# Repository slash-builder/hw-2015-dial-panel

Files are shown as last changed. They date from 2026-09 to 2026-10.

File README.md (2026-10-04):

# Dial Panel · hw-2015

An open hardware device from [SlashBuilder](https://github.com/slash-builder). One device, one repo.

A wall-mounted smart-home panel you print yourself and drive with one dial.
Turn to move, push to open, and it goes back home on its own after a few
seconds. No back button, no smudged glass. A hardware switch cuts the
microphone's power.

> **Status: BETA — not ready for full use.** This repo is public so people can
> look it over and send first-pass feedback, not because the design is done.
> It is well into its test-print cycle: all nine plates have been printed at
> least once, the screen module fits together, and the fit coupons passed — but
> **six plates are pending a reprint**, a full fitting is deliberately deferred
> until they come off the bed, and the dashboard software isn't written.
> Expect dimensions, parts and docs to change.
> [`docs/print-log.md`](docs/print-log.md) is the honest record of what has
> been printed, what failed and why. **Fit reports are the most useful
> contribution this project can get right now.**
>
> It is not published to the print marketplaces, and won't be until there is a
> fully working unit.
>
> The panel's **interaction model** — turn, push, adjust, and the idle reset —
> is written and tested, and you can drive it on a laptop today: see
> [`software/`](software/). The dashboard that uses it is still to come.
>
> [`os/`](os/) builds **Dial OS**: the official Raspberry Pi OS image with this
> device's overlays, users and services already applied. No image has been
> built from it yet — the pipeline is there, the first real build is not done.

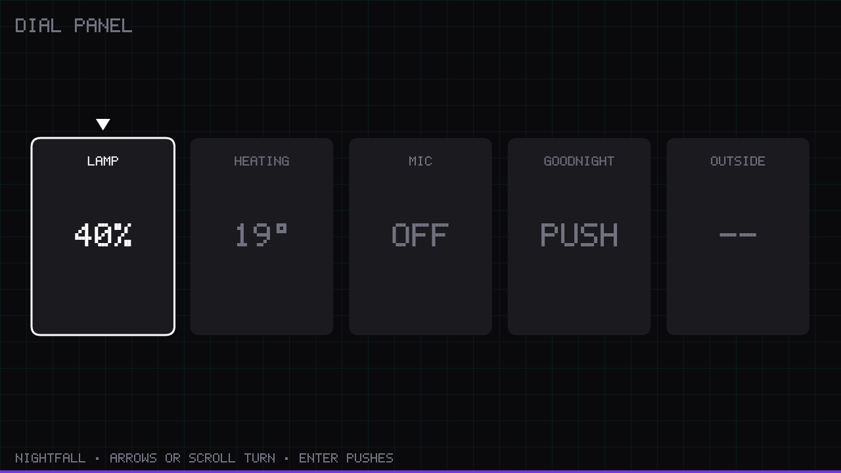
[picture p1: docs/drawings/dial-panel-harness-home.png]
Home screen in the desktop harness


Nightfall

## Pick a team

One release, two looks. Choose once when you build; a Dial Panel keeps its
team for life. The body, trim, dial and gold tab are identical in both;
only the light changes.

| | **A · IGNITION** | **B · NIGHTFALL** |
|---|---|---|
| It's… | a sunrise | a starfield |
| Print | `stl/ignition/04a-band-insert-ignition.stl` | `stl/nightfall/04b-band-insert-nightfall.stl` |
| Light | warm torch | violet, with a cyan grid |

Drawings: [Ignition](docs/drawings/dial-panel-ignition.svg) ·
[Nightfall](docs/drawings/dial-panel-nightfall.svg). More in
[docs/teams.md](docs/teams.md).

## What you need

**Electronics: one Amazon cart.** [`bom/bom.csv`](bom/bom.csv) lists every
part with a checked listing, pack size and per-build cost: a Raspberry Pi 5,
the official 7" Touch Display 2, a KY-040 push dial, a KCD1 rocker, a
MAX98357A amp, a 40 mm speaker, a USB mini mic and WS2812B LEDs.
Roughly **$320 per build** (≈ $450 cart, with spare parts from multi-packs),
prices as of 2026-09-21. Buying the Pi and display from an approved reseller
is cheaper; the BOM notes where.

**Shopping list:** one row per Amazon listing, with how many to add to your cart.
It's generated from [`bom/bom.csv`](bom/bom.csv). The four filaments are included,
so skip any you already own. The Pi kit already includes the power supply and
cooler. Links carry **no affiliate tag**.

<!-- SHOPPING-LIST:BEGIN -->
| Part | Buy | Per build | Listing |
|---|---|---|---|
| Raspberry Pi 5 (4 GB) | 1 | $158.64 | [Amazon](https://www.amazon.com/dp/B0G4R8TSLN) |
| Raspberry Pi Touch Display 2 (7 in) | 1 | $90.00 | [Amazon](https://www.amazon.com/dp/B0DM24QFCF) |
| microSD card | 1 | $23.99 | [Amazon](https://www.amazon.com/dp/B0B7NXBM6P) |
| KY-040 rotary encoder module | 1 | $1.80 | [Amazon](https://www.amazon.com/dp/B07F26CT6B) |
| Mini rocker switch | 1 | $1.09 | [Amazon](https://www.amazon.com/dp/B08683RMVY) |
| I2S amplifier | 1 | $3.44 | [Amazon](https://www.amazon.com/dp/B0DPJRLMDJ) |
| Speaker | 1 | $4.50 | [Amazon](https://www.amazon.com/dp/B01LN8ONG4) |
| USB microphone | 1 | $7.99 | [Amazon](https://www.amazon.com/dp/B01KLRBHGM) |
| USB-A extension (to splice) | 1 | $3.00 | [Amazon](https://www.amazon.com/dp/B0CDC3KQN1) |
| WS2812B LED strip | 2 | $7.79 | [Amazon](https://www.amazon.com/dp/B01CDTED80) |
| Level shifter (recommended) | 1 | $7.25 | [Amazon](https://www.amazon.com/dp/B00XW2L39K) |
| M3 heat-set inserts | 1 | $0.60 | [Amazon](https://www.amazon.com/dp/B0DDWS7BTS) |
| M3 socket-head screws | 1 | $0.50 | [Amazon](https://www.amazon.com/dp/B0GRV5NW7Q) |
| Dupont jumper wires | 1 | $0.90 | [Amazon](https://www.amazon.com/dp/B01EV70C78) |
| Heat-shrink assortment | 1 | $0.25 | [Amazon](https://www.amazon.com/dp/B01MFA3OFA) |
| Filament: matte black PLA | 1 | $8.50 | [Amazon](https://www.amazon.com/dp/B0D7ZYCVTY) |
| Filament: silver silk PLA | 1 | $1.30 | [Amazon](https://www.amazon.com/dp/B0C6QFDQWT) |
| Filament: yellow/gold PLA | 1 | $0.70 | [Amazon](https://www.amazon.com/dp/B0B12W69HT) |
| Filament: clear/natural PETG | 1 | $0.85 | [Amazon](https://www.amazon.com/dp/B085TGGV3L) |
<!-- SHOPPING-LIST:END -->

Wall screws and anchors come from any hardware store. Regenerate this list with
`python3 bom/shopping_list.py` whenever the BOM changes.

**A printer** with a 250 × 210 mm bed or larger (Prusa MK4, Bambu A1, and
similar). Every part prints **without supports**.

**Filament:** matte black PLA (~500 g), silver silk PLA (~75 g), yellow PLA
(a few grams) and clear PETG (~40 g).

**Tools:** a soldering iron (heat-set inserts, amp headers, one wire splice),
a 2.5 mm hex key, and wire strippers.

## What you print

| File | Part | Material | Qty |
|---|---|---|---|
| 01a, 01b | face plates: screen, column | matte black PLA | 1 each |
| 02a, 02b | back shells: screen, column | matte black PLA | 1 each |
| 03 | screen trim | silver silk PLA | 1 |
| 04a **or** 04b | band insert: ember **or** starfield | matte black PLA | 1 |
| 05 | band diffuser (with speaker opening) | clear PETG | 1 |
| 06 | knob | silver silk PLA | 1 |
| 07 | gold tab | yellow PLA | 1 |
| 08 | speaker back-cup | matte black PLA | 1 |
| 11 | wall cleat | matte black PLA | 1 |
| 12 | cleat receiver rail (bolts to the back shell) | matte black PLA | 1 |

Every STL is already in its print orientation and prints without supports.

The panel is two modules (screen and control column) that bolt together:
the 7" screen plus the dial is wider than any common print bed.
Assembled it's **309 × 200 mm and 67 mm off the wall** (85 mm to the knob).

## Printing on a Bambu Lab printer

Open **[`bambu/dial-panel-hw-2015.3mf`](bambu/dial-panel-hw-2015.3mf)** in Bambu Studio. Every
part is already placed, oriented and assigned its filament, on named plates:

| Plate | Parts | Filament | Time (A1) |
|---|---|---|---|
| 1 | face plate, screen | matte black PLA | 1 h 33 m |
| 2 | back shell, screen | matte black PLA | 4 h 31 m |
| 3 | control column: face plate + back shell | matte black PLA | 4 h 30 m |
| 4 | speaker cup, wall cleat, receiver rail | matte black PLA | 39 m |
| 5 | screen trim + knob | silver silk PLA | 37 m |
| 6 | gold tab | yellow PLA | 1 m |
| 7 | band diffuser | clear PETG | 11 m |
| 8 | **A · IGNITION** band insert | matte black PLA | 44 m |
| 9 | **B · NIGHTFALL** band insert | matte black PLA | 39 m |

Print **plates 1–7**, plus **either 8 or 9** for your team: about 12½ hours in
total. The project is set up for the **A1 with a 0.4 mm nozzle** on the
**Textured PEI plate**. On another Bambu printer, switch the printer in Bambu
Studio and re-slice. For other slicers, use the STLs in `stl/`.

## Build

1. **Print** the parts above: the Bambu project, or the STLs, which are already print-oriented.
2. **Inserts:** heat-set the M3 inserts. Every screw goes in from the back, so the face stays clean.
3. **Screen module:** fit the display, with the Pi 5 and cooler on its back, the amp and the speaker (back-cup screwed on behind it).
4. **Column:** fit the dial (held by its own nut), the rocker, the gold tab and the mic cradle.
5. **Wire it:** follow [`docs/wiring.md`](docs/wiring.md) — a pin map, a diagram per subsystem, and the one-wire mic-cut splice. Then append [`docs/config.txt`](docs/config.txt) to the Pi's `/boot/firmware/config.txt`.
6. **Close up:** fit your team's band insert and the diffuser, lay in the LED strips, screw the face plates on, and bolt the two modules together.
7. **Hang it:** screw the cleat to the wall and drop the panel onto it.

**Full step-by-step with a drawing for each step:** [`docs/assembly.md`](docs/assembly.md).

## How it's checked

The CAD in `cad/` is parametric FreeCAD and regenerates every file. Every run checks:

- **Every part:** one clean solid that fits the bed.
- **Openings:** every opening exists (31/31), and there are no unintended ones.
- **Fit:** nothing collides in the assembled position (27/27 part pairs). That
  includes Raspberry Pi's own display model and every screw's full length.
- **Sound:** the path from the speaker through the band stays at least 25% open,
  for both inserts.
- **Hanging:** the wall cleat engages 16.8 mm, and the panel hangs flat against the wall.
- **Printing:** every part sits flat in its print orientation, and every plate slices in Bambu Studio with support off and no warnings.

To regenerate, download Raspberry Pi's Touch Display 2 STEP into
`cad/vendor/` (see `cad/vendor/README.txt`; it's their file, so it isn't
included here) and run
`freecadcmd cad/generate_parts.py`. Then `python3 bambu/build_project.py`
rebuilds the Bambu project and the print-oriented STLs, and slices every plate
as a check. It needs FreeCAD and Bambu Studio installed.

## Known limits

- **Silver silk isn't chrome.** It reads metallic, not mirror.
- **The gold tab is fixed in place** rather than revealed only when the mic is live. The rocker's position shows the mic state.
- **Unconfirmed part dimensions:** a few sizes come from listings and are marked in `cad/README.md`. They include the dial's shaft flat, the rocker's clip thickness and the speaker's depth. Measure your parts; each is a single parameter.
- **LED brightness is capped at about 25%.** Full brightness would pull more current than the Pi's 5 V pins can supply.

## Versions

Every commit on `main` is tagged `vMAJOR.MINOR.PATCH` automatically, patch
counting up. **A tag is a specific printable state of the hardware** — the
CAD, the STLs, the slicer project and the docs as they were together — so if
you print something, note the tag and you can always get back to exactly that
geometry.

This matters more here than in a software repo: a fix can change a part's
dimensions, and a part printed from an older tag may no longer fit one printed
from a newer one. [`docs/print-log.md`](docs/print-log.md) records which parts
changed at each step and what needs reprinting.

Patch bumps happen on their own. Minor and major are deliberate: push a tag
like `v0.2.0` by hand when a release means something, and the automation picks
up from there.

## Repository layout

```
bom/bom.csv          every part, with a checked Amazon listing
cad/                 parametric FreeCAD source + STEP exports + verification notes
cad/vendor/          where Raspberry Pi's display STEP goes (not included)
stl/common/          parts every build prints
stl/ignition/        the A · IGNITION band insert
stl/nightfall/       the B · NIGHTFALL band insert
bambu/               the Bambu Studio project (9 named plates) and the script that builds it
docs/                wiring, config.txt, choosing a team, release drawings
```

## Contributing

Real print reports are the most useful thing you can send: see
[`docs/print-log.md`](docs/print-log.md) for what has been printed so far and
what to check.

Issues and pull requests are welcome, especially fit reports from real
prints (printer, filament, what fit and what didn't). Geometry changes go in
`cad/generate_parts.py`, then regenerate. A change isn't done until every
check in the run still passes.

## License

Code (`cad/generate_parts.py`, `docs/drawings/*.py`) is **Apache-2.0**. Design
files (CAD, STL, drawings, BOM, docs) are **CC-BY-4.0**. See
[LICENSE](LICENSE). Raspberry Pi's display model is theirs and isn't
included.

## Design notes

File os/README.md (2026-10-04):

# Dial OS

A Raspberry Pi OS image with the Dial Panel already set up. Flash it, and the
dial, screen, speaker and lights work on first boot.

```sh
./os/build.sh
```

That is the method. The rest of this file explains what it does and why it is
built this way.

## The idea

**Dial OS is not an operating system we maintain.** It is the official
Raspberry Pi OS release, with a short patch applied: four device-tree overlays
that the device's own `docs/config.txt` already specifies, a user with the
right groups, two systemd units, and the dashboard binary.

That framing is the whole design. Every hour we would spend maintaining a
distribution is an hour not spent on the device. So the build takes an image
Raspberry Pi has already built and tested, unpacks it, changes about twenty
things, and packs it back up. When Raspberry Pi ships a new release, we bump
one checksum and rebuild.

## Why CustomPiOS, and not the two obvious alternatives

| | What it does | Why not here |
|---|---|---|
| **pi-gen** | Builds Raspberry Pi OS from scratch with `debootstrap`. It is the tool Raspberry Pi builds the real thing with. | We would be rebuilding an entire OS to add four config lines. All of the cost of building from scratch, almost none of the benefit — right if we needed to *remove* a lot or change the base, and we do not. |
| **rpi-image-gen** | Raspberry Pi's own newer, declarative layer/config/hook builder. Structurally the nicer tool. | Its supported hosts are **arm64 Debian**, so it needs a Pi or an arm64 builder we do not have free — and it is explicitly under active development, which is a poor foundation under a device we want strangers to flash. Worth revisiting; see "When to switch". |
| **CustomPiOS** ✅ | Opens a released image, modifies it in a chroot, repacks it. | Builds on x86_64 in Docker, so it runs on the build fleet we already have. Minutes, not an hour. And it is the proven path for exactly this shape of product — OctoPi, MainsailOS and FluiddPi are all appliance distributions for printed hardware, all built this way. |

The decisive argument is not the first build, it is the tenth. Starting from
the released image means we inherit Raspberry Pi's firmware, kernel, overlays
and testing for free, forever, instead of re-deriving them.

## What the build actually does

1. **Fetches a pinned base image** and verifies its SHA-256 — every run, not
   just after downloading, because a truncated file from an interrupted run
   looks exactly like a good one.
2. **Stages the generated pieces.** The boot overlays are copied from
   `docs/config.txt`, the device's own source of truth for how it is wired. They
   are never retyped here; a second copy of the pin assignments would be wrong
   the first time a pin moved.
3. **Runs CustomPiOS**, which unpacks the image, runs
   `modules/dialos/start_chroot_script` inside it, and repacks it.

`start_chroot_script` is worth reading directly — it is the clearest
description anywhere of what Dial OS is.

## Setting one up

This is the part that has to be easy, because the people flashing it have just
spent two days printing an enclosure and do not want a second project.

**Everything that needs a keyboard happens before the card is written.**
Raspberry Pi Imager already asks for Wi-Fi, hostname, user and SSH, on a real
keyboard, and writes them into the image. Dial OS leaves that mechanism
completely untouched. Asking again on a device whose only input is one knob
would be a worse version of a solved problem.

**Everything else happens on the dial**, because it is a question about a thing
you are holding:

- **Which team.** IGNITION or NIGHTFALL — turn, push, done. One image ships
  both, matching a release that ships both printed band inserts. One device,
  one team, for its life; the software never offers to change it afterwards.
- **Dial calibration.** A KY-040 may be 20-detent/20-pulse or 30-detent/15-pulse
  and *nothing on the part says which*. Guess wrong and the dial moves two
  tiles per click, which feels broken — and most people will assume they
  soldered it wrong. So `calibrate-dial.sh` measures it: turn the dial one full
  turn, and the count goes in `dial.toml`. The dashboard scales by it, so there
  is no reboot; setting `steps-per-period` in `config.txt` would work equally
  well but costs a restart in someone's first five minutes with the thing.

So the whole setup is: flash, boot, pick a team, turn the dial once.

### Getting it into Raspberry Pi Imager

CustomPiOS generates an `os_list` entry from the `RPI_IMAGER_*` values in
[`config`](config). Published alongside a release, that lets a builder point
Imager's **Content Repository** at SlashBuilder and pick "Dial OS" from the
same list as Raspberry Pi OS itself — no separate installer, nothing to follow.

Until that is published, **Use Custom** with the downloaded `.img.xz` works and
needs no infrastructure at all.

## Two ways in

`start_chroot_script` is ordinary shell that happens to run in a chroot.
Nothing in it assumes it is running inside a build. That is deliberate: the
same script can run on a live Raspberry Pi to convert a working Pi OS install
into a Dial Panel, which is what you want when someone already has a card they
like, or when you are bringing up the bench unit and do not want to reflash to
change one thing.

The image is the front door. The script is the side door. There is only one
set of instructions to keep correct.

## Bumping the base image

Edit [`base-image.conf`](base-image.conf): release date, filename, URL,
SHA-256. Take the checksum from the `.sha256` file Raspberry Pi publishes next
to the image, not from a mirror.

It is pinned rather than tracking latest because a build that silently follows
`latest` is a build you cannot reproduce when someone reports a bug against an
image you shipped three months ago.

## Verified, and not

**Verified:** every script passes `shellcheck` and `bash -n`; the pinned URL
resolves (HTTP 200, 541 MB, correct `xz` magic bytes) and its checksum matches
the one Raspberry Pi publishes.

**Not yet verified: a real image has not been built from this.** That needs a
Linux host with Docker and privileged loopback mounts — a build agent, not a
laptop — and the first real run is where the remaining unknowns live: the
`.img.xz` variant handling, whether `set_config_var` behaves on Trixie's
`config.txt`, and whether disabling `getty@tty1` leaves a usable recovery path.
None of it is exotic, but none of it is proven, and this file will not claim
otherwise until an image has booted a Pi.

## Decided: Trixie (DJ, 2026-10-04)

This builds on **Trixie**, because that is what Raspberry Pi OS is now: the 2026-09-15 release is `raspios-trixie-arm64-lite`. DJ ruled
on 2026-10-04 to accept the base bump, and `docs/config.txt`'s header now says Trixie to match.

Starting a new device on the *previous* base is the same mistake as building on an end-of-life Yocto branch, which this studio is
already paying for elsewhere. What would reopen this is evidence that a specific overlay this device needs, most likely `ws2812-pio`
(RP1-era and new), behaves differently on Trixie. That is a bench test, not an opinion, and it belongs in the first-boot story. The
overlay names in `docs/config.txt` were checked against the firmware README on 2026-09-21 and have **not** been re-checked against Trixie.

## When to switch to rpi-image-gen

Not now, but the trigger is worth naming so the decision gets made rather than
drifted past: if Dial OS ever needs to *subtract* substantially from Pi OS —
strip the package set hard, change the init, produce an A/B-updatable root —
then modifying a released image stops being the cheap option and a declarative
builder starts being worth an arm64 build host. Until then, the cheapest
correct thing is to patch what Raspberry Pi already ships.

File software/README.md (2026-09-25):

# Dial Panel software

Two crates. One is the device's behaviour; the other is a way to look at it
without a Raspberry Pi in front of you.

```
dial-nav/   the interaction model, as pure logic — no I/O, no clock, no hardware
dial-sim/   a desktop harness: the same logic, drawn in a window on your laptop
```

## Why it is split this way

The panel's behaviour is the part worth getting right, and it is the part that
is painful to iterate on if every change means flashing a card and walking over
to a bench. So `dial-nav` contains **no device at all**:

- input arrives as events — `Turn(detents)`, `Push`
- time arrives as `Tick(duration)`; the crate never reads a clock
- output is a `Frame` a host draws however it likes, plus a list of `Effect`s
  the host may act on — light an LED, play a tone, switch a relay

Nothing in it touches GPIO, opens a file, or knows what it is running on. That
is what lets the same state machine run under the harness and on the panel
unchanged — and it is why the eight-second idle reset can be tested in
microseconds instead of eight seconds.

It also means this logic can be lifted into a shared Kit later without a
rewrite, which is the intent.

## The interaction model

Turn to move focus. Push to open. Turn to adjust inside a tile. **There is no
back button** — you leave a tile by pushing, or by letting it time out and go
home on its own after about eight seconds, which the screen shows as a draining
line and the words "HOME IN n".

Tiles come in four kinds, because not everything wants a screen:

| Kind | Push | Turn inside |
|---|---|---|
| `Range` | opens it | adjusts the value live |
| `Toggle` | flips it, stays home | — |
| `Action` | fires it, stays home | — |
| `Info` | opens it to be read | nothing |

Adjustment is **live**, not a dialog you confirm: turning a dimmer dims the
lamp. So leaving a tile — deliberately or by timeout — keeps what you set.
There is nothing to cancel, which is what makes a device with no back button
safe to walk away from.

## Run the harness

```sh
cargo run -p dial-sim                      # IGNITION
cargo run -p dial-sim -- nightfall         # NIGHTFALL
```

```
← →  or scroll     turn the dial
Enter / Space      push
Esc                quit
```

The window is the panel's real geometry: the 7" Touch Display 2 is a 720×1280
portrait panel mounted landscape, so 1280×720.

There is deliberately **no key that acts as "back"**. The device does not have
one, and a harness that quietly added one would be testing a device nobody is
building.

## Render without a display

```sh
cargo run -p dial-sim -- nightfall --shots /tmp/shots
```

Writes a PNG per state — home, a toggle switched on, a tile open, a tile
mid-countdown — with no window and no display. This is how the renderer gets
checked on a build machine, and it is the difference between "it compiled" and
knowing what it actually draws.

## Test

```sh
cargo test -p dial-nav
```

Twenty-three tests, no hardware. Each one is a line from the concept sheet
stated as an assertion — that an open tile goes home at eight seconds and not at
7.999, that any touch of the dial restarts the countdown, that the home screen
never counts down because it has nowhere to go, that pushing out of a tile lands
all the way home with no intermediate level.

## What this is not

**It is not a decision about the shipped shell.** Which framework the device's
real dashboard is built on — Flutter Embedded Linux, Slint, or Rust drawing
straight to the framebuffer — is an open question with a benchmark of its own
(THUN-24). `dial-sim` uses `winit` + `softbuffer` + `tiny-skia` because they are
small, pure Rust and run anywhere; that choice binds the harness and nothing
else.

**It is not the dashboard.** There is no Hearth client here, no home-automation
integration, no LED or audio output — those are separate pieces of work, and
this one deliberately stops at the seam so they can be written against a
behaviour that is already proven.

## Two things left open on purpose

Both are exposed as configuration rather than settled in code, because they are
`ux-engineer`'s and DJ's calls, not the state machine's:

- **`idle_timeout`** — the concept says "about 8 seconds". Whether it is
  adjustable, and by whom, is undecided.
- **`idle_resets_focus`** — when the panel goes home on its own, should focus
  return to the first tile? Default is no: going home is about leaving a tile,
  not forgetting where you were standing. A wall panel that always greets you at
  the same tile is a defensible other answer.

Still unanswered elsewhere, and deliberately not invented here: hold-screens, a
long-press escape hatch, and whether the panel accepts touch at all or is
dial-only.

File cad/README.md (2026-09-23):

# Thunderhead 2015 — Concept 13 "Dial Panel" — wall-mounted smart-home panel

Parametric, FreeCAD-native (`Part` module) CAD for the real, printable Dial
Panel — a wall-mounted Home Assistant-class hub built around the Raspberry
Pi Touch Display 2 (7", landscape), a KY-040/EC11 rotary encoder with push,
a KCD1 mic-cut rocker, and a backlit perforated "band" that doubles as the
speaker grille. SlashBuilder open-hardware release track.

Built 2026-09-21. Run headless via:

```sh
freecadcmd cad/generate_parts.py
```

**This has been run and verified** — every part's own STEP is read back and
checked (solids==1, `isValid()`, shells==1, bbox vs. the 250×210×210mm bed),
every declared opening is probed with a real boolean intersection, a
no-unintended-openings ray grid runs over both face-plates, a full
assembly-interference pass runs the real Raspberry Pi display STEP
(transformed to its actual installed position) plus envelope boxes for
every other component against the real exported shell geometry, a
**sound-path check** fires a ray grid along the driver's own axis through
every band layer stacked in its installed position (not just each part in
isolation), and the **wall-cleat is verified in its actual engaged
position** against the integrated receiver (zero bulk interference, a real
sub-0.3mm contact gap at the 45° hook faces, ≥8mm engagement depth). See
"Verification" below for the numbers.

**Revision 2 (2026-09-21, same day):** an independent
independent review of `assembly-reference.step` found two defects neither
the original checks nor the original build caught — the speaker firing
into 05-band-diffuser's own solid plastic (with both band inserts too
sparse over the driver even once that's fixed), and the wall-cleat sitting
28mm behind the back-shell with no engagement shown at all. Both are fixed
in this revision; see "Real defects found and fixed" below for the full
writeup of each, and "Design decisions / deviations" for the seam call-out
this review also asked to be stated plainly.

**Revision 3 (2026-09-21, same day):** an independent
follow-up check of revision 2's newly-engaged cleat found the "wall
plane" it reported (55.02mm) was actually the cleat's FRONT (hook) face,
not its REAR (wall-mounting) face — and, checking the real rear face
instead, found both back-shells standing 0.3–0.5mm *into* that actual
wall plane, with their own two back-most points 0.26mm apart (not
coplanar with each other, which would make a hung panel rock). Fixed
with one shared `BACK_PLANE_Y` constant driving both shells and the
engaged cleat; see "Wall-cleat engagement" under Verification and "Real
defects" #10 for the full writeup and the corrected numbers (the
wall-to-front-face distance is 66.56mm, not 55.02mm).

**Not yet printed or physically fitted.** Pre-release: CAD-verified, not yet printed.

## Why this is TWO bolt-together modules, not one face-plate/back-shell pair

The task's own hard constraint is a 250×210×210mm bed. The real Touch
Display 2 is 189.32mm wide landscape; the control column needs ≥62mm clear
for the 24-detent dial ring alone. Even with *every* margin driven to
zero — impossible in practice — 189.32 + 62 = 251.32mm, already over the
250mm limit before a single millimetre of rim, gap, or wall is added. A
single-piece face-plate/back-shell spanning both zones cannot print on this
bed at any real hardware size, independent of how tightly the script trims
its own margins. This is the same wall the studio's Cel open-build hit
("Cel became two modules because it is wider than any bed" —
`thunderhead-2015-open-build-reconsideration.md`) — and the concept sheet's
own front elevation already draws the control column as a visually distinct
inset rect with its own border, so a bolt-together seam there is a faithful
realisation of the concept's own visual language, not a deviation from it.

**Fix:** split into a SCREEN module (01a/02a) and a CONTROL-COLUMN module
(01b/02b), joined by 4× M3 through-bolts across the seam wall (screws span
the open cavity from 02a's clearance holes into 02b's blind bosses — no
continuous pillar needed, just aligned holes). Each module is independently
≤250mm and independently verified.

## Assembled size

| | Width | Height | Depth |
|---|---|---|---|
| **Assembled (both modules)** | **309.32mm** | **200.24mm** | **66.56mm** (deepest module — both modules' backs are now exactly coplanar at this value, see "Wall-cleat engagement" below) |
| Screen module (01a+02a) | 219.32mm | 200.24mm | 54.56mm |
| Column module (01b+02b) | 90.00mm | 200.24mm | 66.56mm |
| Task target | ~248mm | ~196mm | ~50mm |

**Deviation from the target, flagged:**

| Axis | Target | Built | Why |
|---|---|---|---|
| Width | 248mm | 309.32mm (+25%) | Real display (189.32mm landscape) + real 24-detent dial ring (62mm min) + real perimeter-mount rim clearance genuinely cannot fit narrower **and cannot fit one bed at all regardless** (see above) — this is the same "real hardware is bigger than the concept's placeholder screen guess" growth every other 2015 open-build hit, compounded by the bed-width wall forcing a two-module split with its own seam margins |
| Height | 196mm | 200.24mm (+2%) | Essentially on target — real display height (120.24mm) + real band/speaker zone dominate, both close to the concept's own proportions |
| Depth | 50mm | 54.56mm screen / 66.56mm column (+9% / +33%) | Screen module depth is the real Pi5+Active-Cooler+display stack, computed not guessed, and lands close to target. Column module is **genuinely deeper** than the screen module — a real, BOM-driven consequence: the USB mic extension's own female-end overmold (BOM: pad to a 20×12×45mm pocket) plus the protruding mic dongle need ~52mm of straight clearance, which the screen module's own depth doesn't have room for. This is an honest stepped back profile, not a forced simplification — see "Design decisions" below |

## Part table

| # | File | Material / colour | Qty | Print orientation | Support | Notes |
|---|---|---|---|---|---|---|
| 01a | `01a-face-plate-screen` | Black PLA (matte) | 1 | Front face DOWN | None | Screen window, band window, band-insert/trim/perimeter blind bosses on the back. **Round 6: front trim rebate REMOVED** (see "First real print report" below) — the front face is one flat plane apart from real through-openings; trim(03) mounting is now a widened TRIM_BORE_D bore (admits the trim's own pass-through boss), not a plain screw clearance hole. **Round 8: perimeter bosses repositioned off a real FIT_CLEARANCE from the shell's inner wall AND the display's own real edge** (see "Round 8" below) — the one right-side boss position (`_PA_XR`) also uses a smaller, position-specific OD (`PERIM_BOSS_OD_TIGHT`, ≤9mm) where the display leaves less room than the standard boss needs |
| 01b | `01b-face-plate-column` | Black PLA (matte) | 1 | Front face DOWN (flat — see below) | None | 24-detent tick ring, ENGRAVED ~0.6mm into the front (only intentional front relief; changed from raised this pass — see "Print-orientation checks"), KY-040 bushing hole + local thinned zone, rocker cutout + local thinned zone, gold-tab pocket |
| 02a | `02a-back-shell-screen` | Black PLA (matte) | 1 | **BACK-WALL DOWN** (changed round 5 — see "Print-orientation checks") | None | Display retention, Pi5/cooler clearance + vents, sealed speaker pod (tapered lead-in, now harmless not load-bearing) + amp/level-shifter POCKETS, band LED groove, wall-wash LED channel, cable slot, seam clearance, registration recess + 3× M3 clearance holes for the separate 12-cleat-receiver-rail |
| 02b | `02b-back-shell-column` | Black PLA (matte) | 1 | **BACK-WALL DOWN** (changed round 5 — see "Print-orientation checks") | None | Mic ports + cradle shelf (round 5: extended to the true back wall, now a full support partition, not a floating shelf), KY-040 anti-rotation tab, rocker clearance, seam bosses (round 5: each with its own support rib to the back wall), perimeter mounts, wall-wash LED channel |
| 03 | `03-screen-trim` | Silver silk PLA | 1 | Flat, front face down | None | Chrome bezel ring. **Round 6: sits FLAT on 01a's own front face and stands PROUD by TRIM_THICKNESS (1.5mm)** — no longer flush in a rebate (see "First real print report" below). Mounting boss passes THROUGH 01a's own widened bore into open cavity air, insert bored from the boss's own tip; screwed from the cavity side, same "never a visible fastener" rule as before. **Round 8, FLAGGED for sign-off:** all 4 mounting bosses now touch the real display at Y-depth (only ~3.1mm of real room behind 01a before the display's own front face, well under the 7.1mm a full M3 heat-set insert needs) — fastener changed from an M3 heat-set insert to a self-tapping screw directly into a shortened boss (`TRIM_PILOT_D=2.6mm` pilot, `trim_boss_len` capped to what real space allows). This is a genuine design deviation, not a geometry nudge — see "Round 8" below |
| 04a | `04a-band-insert-ignition` | Black PLA (matte) | 1 (of 2 variants) | Flat, front face down | None | "Ember" hex-staggered perforation: base grid 3.2mm holes/6.5mm pitch outside the acoustic zone, a denser 3.5mm/5.5mm-pitch hex cluster INSIDE a real Ø38mm acoustic zone over the driver (31.4% open there), 143 holes total, 16.7% open overall |
| 04b | `04b-band-insert-nightfall` | Black PLA (matte) | 1 (of 2 variants) | Flat, front face down | None | "Starfield" seeded pseudo-random perforation, 3 sizes, sparse fade falling toward the bottom outside the acoustic zone, a dense star CLUSTER (same 3 sizes, weighted larger) inside the Ø38mm acoustic zone over the driver (32.1% open there), 117 holes total, 9.0% open overall |
| 05 | `05-band-diffuser` | Natural/clear PETG, ~1mm | 1 | Flat, either face down | None | Solid everywhere EXCEPT a real Ø38mm acoustic opening over the driver's own firing axis (matches the cone) — diffuses LED light through whichever insert's light-zone holes are fitted, doesn't block the speaker |
| 06 | `06-knob` | Silver silk PLA | 1 | Flat mounting-face down | None | Ø30×18mm, D-bore 6.1/4.6mm, radial M3 set-screw pilot, pointer groove |
| 07 | `07-gold-tab` | Yellow/gold PLA | 1 | Flat, either face down | None | Static press-fit tab (documented deviation from the "mechanical reveal" in the xxx5 guide — task-specified) |
| 08 | `08-speaker-back-cup` | Black PLA (matte) | 1 | Flange face down | None | Seals the pod from behind, plug seal + recess for the 30–60cc sealed chamber, 4× M3 into 02a, cable pass-through |
| 11 | `11-wall-cleat` | Black PLA (matte) | 1 | Flat BOTTOM face down, no rotation | None | 45° french cleat, 180×11.9×13.9mm (cross-section DERIVED so the engaged rear face lands exactly on `BACK_PLANE_Y` — see "Real defects"), 2× countersunk wood-screw holes, verified ENGAGED and coplanar against 02a+rail/02b in the assembly reference |
| 12 | `12-cleat-receiver-rail` | Black PLA (matte) | 1 | Flat mounting-face (tongue) DOWN | None | **NEW, round 5.** The french-cleat receiver ridge, split OFF 02a into its own printed part (see "Round 5" below) — reproduces the old fused wedge's exact geometry/position; 3× M3 into its own blind heat-set inserts, screwed to 02a from inside the cavity |

## Round 5 — cleat rail split off, 02a/02b flipped to back-wall-DOWN

Coordinator decision after round 4b's real-slicing pass (see "Print-
orientation checks" below) still showed both 02a and 02b's flat back
walls bridging the whole tub with nothing under them, open-front-DOWN:
the correct print orientation for a tub is open-side UP (back wall on
the bed), not open-front down. 02b already measured 95.9% bed contact
back-down; 02a was blocked only by its own integrated 45° cleat-
receiver ridge, which used to protrude 12mm past the back wall and
become the new low point when flipped.

**Fix, three parts:**

1. **The cleat receiver is now its own printed part**, `12-cleat-
   receiver-rail` (black PLA) — built from the exact same wire/points
   the old fused wedge used, so its world position is bit-for-bit
   identical, and the wall-cleat engagement math needed no changes.
   Bolts to 02a's back wall with 3× M3 into its own blind heat-set
   inserts; screws driven from inside 02a's cavity (before 01a closes
   it up) through plain clearance holes, countersunk on the cavity
   side — hidden once assembled, and hidden again once hung. 02a gets
   a shallow 0.7mm registration recess (the old wedge's own 0.5mm real-
   overlap sliver, now a real self-jigging tongue) plus the 3 holes.
   Print orientation: flat mounting face (the tongue) down — zero
   support, matching the coordinator's own "a 45° wedge usually prints
   lying on its flat back."
2. **02a and 02b now print BACK-WALL DOWN** (`PRINT_ORIENTATIONS`
   changed from `Vector(0,-1,0)` to `Vector(0,1,0)`). Every remaining
   boss/tube/tab extends FROM the back wall TOWARD the open rim —
   columns rising from a base, self-supporting by construction — so
   the old 45° tapers on the speaker-pod tube and the KY-040 tab are
   no longer load-bearing (left in place; harmless).
3. **Two NEW defects found only by direct isolation against the real
   slicer** (Bambu Studio, supports off) after the flip — neither was
   caught by `overhang_scan()`, which only sees PLANAR faces:
   - **02b's mic-cradle shelf** (fused only to the two side walls,
     spanning the full width) sat ~49mm above the true floor with
     nothing under it — a genuine floating cantilever, not a bridge.
     Fixed by extending the shelf's own depth to reach the true back
     wall exactly (not past it — see the pod-tube overshoot Gotcha
     below), turning it into a full support partition.
   - **02b's seam-bolt bosses** (Ø9mm pegs, anchored only at the side
     wall, sticking sideways into open cavity air at Y=y0+15 — only
     15mm out of a 66.56mm total depth, i.e. near the very top of the
     new ~63.5mm vertical stack) triggered Bambu's own "floating
     cantilever" warning even after every other feature was fixed.
     Found by disabling one fused/cut feature at a time and re-slicing
     for real, not by extending `overhang_scan()` (a round cylinder's
     surface isn't planar, so that scan can't see this class at all —
     documented directly in its own docstring now). Fixed with a real
     support rib running from each boss straight down to the back
     wall, the same "reach the floor" fix as the mic-cradle shelf.

**Gotcha found (twice) this round:** a cylinder/box built with a
defensive "+0.5mm/+1.0mm real overlap margin" at its FAR end, meant to
guarantee a valid fuse, silently overshoots the part's own true outer
face by that margin. Harmless in the old open-front-DOWN orientation
(the overshoot was up at the open rim, nowhere near the bed) — but
once back-wall-DOWN made that outer face the bed-contact plane, the
overshoot became the part's own new lowest point, standing the
ENTIRE flat back wall off the bed (1.9% first-layer contact instead
of ~90%+, or 0.0% in the shelf's case). Hit on the speaker-pod tube
(02a) and the mic-cradle shelf (02b) independently; fixed both by
ending exactly at the true outer face, never past it — the shell
already has real solid material out to that face, so no defensive
margin is needed there.

**Result:** `python3 bambu/build_project.py` from the repo root now
exits 0 — every plate slices with ZERO warnings, confirmed by direct
re-run, not just inferred from `generate_parts.py`'s own checks.
`cad/print_rotations.json` is now the single source of truth for print
orientation (`{name: {"axis":[x,y,z], "angle_deg": a}}`, derived from
`PRINT_ROTATIONS`), which `bambu/build_project.py` reads directly.

## Round 6 — first real print report: 01a's front trim rebate failed

DJ printed 01a for real. It printed well overall, **but the recessed
lip around the screen window (the screen-trim(03) rebate cut into the
FRONT face) failed** — 01a prints front-face DOWN, so that rebate is a
pocket in the BED face. Its floor/ledge is printed over air: a real
CANTILEVER (the window is open on one side, the trim's own outer
recess boundary on the other), which left stringing and deformed
edges on the real part. **Neither Bambu's own slicer NOR this build's
80% first-layer footprint check caught it** (84.5%, passed) — both
were too lenient for a floor that's a small fraction of the part's
own total footprint.

**DJ's decision: drop the rebate.** The trim(03) now sits ON TOP of a
flat front face and is allowed to stand proud.

**Fix, three parts:**

1. **01a**: the front trim rebate is REMOVED entirely. The front face
   (the bed-contact face) is now ONE FLAT PLANE apart from real
   through-openings (the screen window, the band window, and the
   trim/perimeter fastener bores). Confirmed by `bed_face_scan()`
   below: 100% first-layer contact (was 84.5%), **zero** downward-
   facing bed-height regions found at all.
2. **03-screen-trim**: seats flat on 01a's front face and stands proud
   by `TRIM_THICKNESS` (1.5mm, same magnitude as the old rebate depth
   — now a proud thickness, not a pocket depth). Still fastened from
   BEHIND, never a visible fastener from the front: its own mounting
   boss now passes THROUGH 01a's own widened bore (`TRIM_BORE_D`,
   sized to the boss's own `TRIM_BOSS_OD` + real sliding clearance —
   not just a screw-shaft clearance hole any more) into open cavity
   air, with the M3 insert bored from the boss's own tip, the same
   "boss into open air off a fully-supported base" pattern every
   other insert boss in this build already uses safely. Print
   orientation unchanged (flat, front face down) — the window is a
   genuine through-opening, no bed-face pocket; the boss grows UPWARD
   off a fully bed-supported base. Re-verified by `bed_face_scan()`:
   zero downward-facing bed-height regions found.
3. **Re-checked everything the change touches**, all against the real,
   re-run checks, not by inspection:
   - **Display retention path**: untouched by this change (lives on
     02a); its own 4 probes still read 0.00% blocked, unchanged.
   - **Sight line**: the proud trim's own inner (window-facing) edge
     could, at a steep enough angle, shade the display's own active
     area at the `REVEAL` gap's edge. Added a real, computed, asserted
     check: `atan(REVEAL / TRIM_THICKNESS)` = **33.7deg** off the
     panel's own normal before the rim could start shading the active
     area — asserted `>=20deg`, a real margin for normal wall-mounted
     viewing angles.
   - **Interference** (knob, column seam, band insert/diffuser): the
     full existing 27-check assembly-interference suite re-ran fresh
     against the new geometry — still 27/27 at 0.000mm³. (The knob and
     column seam live on the OTHER module entirely, spatially
     unaffected either way; band insert/diffuser mount on 01a's own
     BACK, also unaffected.)
   - **Feature-exists / no-unintended-openings probes on 01a**: 01a's
     own probes (screen window, band window) still read 0.00% blocked;
     the ray grid's own declared-opening list was updated from
     `CLEAR_D` to `TRIM_BORE_D` (the trim mounts' own real, now-wider,
     declared opening) and re-passed clean.
   - **Chrome ≤20%**: unchanged, 6.9% (the 2D footprint math doesn't
     care whether the trim sits flush or proud).

### NEW CHECK — bed-face pockets and ledges (`bed_face_scan()`)

The class of defect that slipped through: a downward-facing surface,
above the bed, with only air beneath it down to the bed (or to lower
material) — a bridge if supported on two opposite sides, a cantilever
if supported on only one (or none), however narrow. Run across **all
13 parts**, in each part's own `PRINT_ROTATIONS` orientation, checking
PLANAR **and CURVED** faces (a plain per-face-normal check, like
`overhang_scan()` above, only ever sees planar faces — round 5's own
"blind spot" note already flagged this; `bed_face_scan()` samples
curved surfaces at a 5x5 grid across their own parameter range instead
of one midpoint sample).

**Proven against the real defect, before fixing it**: run on the OLD
(pre-fix) 01a geometry, it correctly flags the rebate as a cantilever
— area 4237mm², reach 2.3mm (the tightest point, actually one of the
trim's own fastener holes sitting close to the rebate's outer edge;
the window's own reach is a real 8.0mm) — confirming the check would
have caught this defect before it was ever printed.

**Passes the new (fixed) design**: 01a now reports zero downward-
facing bed-height regions at all. 03 likewise.

**Everything else it flagged, with real numbers** (per the task's own
request to report these, not just silence them):

- **01b's 24 engraved detent ticks**: all classify as tiny bridges or
  small slots, spans 1.0–6.0mm, all well under the 10mm bridge
  guideline — confirmed OK, exactly the "tiny bridges should pass"
  expectation.
- **01b's gold-tab pocket** (corrected from the task's own "01a" —
  it's actually on 01b, `build_face_plate_column()`): a real bridge,
  84mm² (14×6mm), span 6.0mm — under the 10mm guideline, OK.
- **06-knob's D-bore floor**: a bridge, 26mm², span 5.1mm — OK. (Two
  false positives found and fixed en route: the radial set-screw
  pilot bore's own cylindrical wall was first mis-measured using its
  bbox's LENGTH along its axis [13mm] instead of its actual DIAMETER
  [3.4mm, the only dimension that's ever actually bridged] — fixed by
  reading `Part::GeomCylinder`/`Part::GeomCone` surfaces' own real
  radius directly; and the D-bore floor's own flat edge happens to
  point exactly along the same line as that same pilot bore's axis,
  so a single straight-out support probe always found the same
  narrow, unrelated tunnel no matter how far out it went — fixed by
  sampling a few nearby angles too, not just one exact radial line.)
- **11-wall-cleat's wood-screw clearance bores**: small, diameter
  4.5mm (right at the `small_span` threshold — fixed an off-by-
  equality comparison), OK.
- **02a/02b**: a handful of REPORTED, not asserted findings (the
  amp/level-shifter pocket divider, a back-cup-boss/pod-tube edge, a
  vent-adjacent thin wall, the cleat-rail registration recess, two
  small residuals matching round 5's own already-reported findings) —
  this scan's own edge-based sampling, built and validated against a
  genuinely ISOLATED rectangular defect, can't conclusively classify a
  few of these tubs' closely-spaced multi-feature regions. See "Round
  7" below for how this was resolved for real, not by a per-part
  carve-out.

## Round 7 — bed_face_scan() tightened; the two >10mm findings fixed

Coordinator review of round 6: the check REPORTED (didn't assert) two
real cantilevers on 02a, both wider than the 10mm bridge guideline —
"Bambu not warning is weak evidence: it didn't warn about the rebate
DJ's print actually failed on either." Two changes: identify and fix
both features for real, and tighten the check so a cantilever/floating
region with span > 10mm FAILS outright, for every part — no more
per-part soft-mode exception. Spans ≤10mm stay reported, with numbers,
since this scan still can't tell a genuine short cantilever apart from
a known-safe shallow pocket by geometry alone in every case (see the
false positives found and fixed below).

**The two features, identified:**

1. **The band-LED channel groove's own "ceiling"** (area 200mm²,
   reported span 44.4mm, bbox `(-67.2,11.0)-(-22.8,21.0)`) —
   `build_back_shell_screen()`'s band-LED groove, a shallow
   (`POCKET_DEPTH`=1.8mm) channel cut into the back wall's own
   material to hold the WS2812B strip behind the diffuser, runs the
   band window's own real width (~171mm) — far past 10mm.
2. **The cable slot's own "ceiling"** (area 48mm², span 16.0mm, bbox
   `(-113.0,0.0)-(-97.0,3.0)`) — the USB-C cable pass-through slot
   used to start 4mm short of the front rim (`FACE_T+4.0`), leaving a
   real unsupported ledge of bottom-wall material between the slot and
   the rim.

**Cable slot — fixed for real, confirmed by real slicing.** Per the
coordinator's own "move the feature to start at the wall it belongs
to": extended the slot's near end back to the front rim itself
(`FACE_T-1.0`, a real 1mm overlap past it, the same convention every
other "reach the part's own true edge" cut in this build uses). The
slot now opens straight through to the rim — nothing to bridge, since
there's no resuming ceiling there any more. `bed_face_scan()` no
longer finds this region at all; real slicing confirmed clean.

**Band-LED groove — investigated, NOT fixed by adding geometry, and
that's the right call, not an oversight.** Two gusset (rib) attempts
were built and BOTH made things WORSE or did nothing, confirmed by
direct re-slicing, not just by this build's own checks:

- *First attempt*: narrow (2mm) full-depth ribs at even intervals,
  splitting the channel into ≤10mm segments. Real slicing
  (`bambu/build_project.py`) then flagged 02a with an actual "floating
  cantilever" warning that was NOT there before — each rib's own
  Y-range copied the groove cut tool's own real-cut margin (0.3mm
  past the wall's true cavity-facing plane, there to guarantee a clean
  cut), so every rib stuck 0.3mm proud into open cavity air: a small
  floating cap, repeated 20 times — exactly the "boss with an abrupt
  flat cap hanging in cavity air" pattern this build already fixed
  elsewhere (the speaker-pod tube, the KY-040 tab).
- *Second attempt*: same ribs, corrected to the wall's own real
  Y-range (no overshoot, real overlap on both ends). Real slicing came
  back clean — but `generate_parts.py`'s OWN check still reported the
  *exact same* 200mm²/44.4mm finding, byte-for-byte unchanged by the
  ribs. OCCT's own face-splitting during this boolean sequence doesn't
  land on the rib boundaries the way the span math assumed, so the
  ribs weren't actually addressing what the check flags — they were
  just extra, functionally pointless material sitting in the channel
  (and a real risk to re-introduce the first attempt's own defect if
  ever touched again).

Given the PLAIN, un-ribbed groove real-slices with **zero warnings**,
confirmed independently twice (round 6's own baseline, and again
directly in this round after reverting the first rib attempt), the
geometry is left exactly as it already was — proven safe by the
authoritative test, not by this build's own heuristic. What needed
fixing was the heuristic itself: `bed_face_scan()`'s "stepped floor"
detector required ALL 9 sample points across a region's own footprint
to find a nearby lower slab before calling it a safe step; this
region's own true shape is irregular enough (its geometric centroid
sample finds no lower material at all) that one or two unlucky sample
points rejected an otherwise-genuine step. Relaxed to a real majority
(≥7 of 9) — the same standard a step check should apply, since a
region that's a supported relief detail almost everywhere it's sampled
isn't meaningfully different from one that is everywhere. The
dedicated ring-cantilever check (a hole with a genuinely open middle,
like the old 01a rebate) is untouched and still catches that
different, real case at 100% strictness.

**Result, both confirmed by direct re-run:** `generate_parts.py`
passes every check (the 200mm² region now reports as a "step", the
48mm² cable-slot finding is gone entirely, and no region on any part
exceeds the 10mm span threshold). `python3 bambu/build_project.py`
exits 0, every plate, zero warnings — checked twice.

## Round 8 — real assembly failure: neither face plate seated; the interference check's own pair list was the root cause

DJ printed plates 1, 2 and 3 for real and tried to assemble them.
**Neither face plate seats into its own shell** — "the screw base bumps
the edge of the body." Measured directly on the repo's own exported STEP
files, placed by `cad/assembly_placements.json`: 01a vs 02a overlapped by
448.43mm³ (6 regions, the perimeter screw bosses biting ~2mm into the
shell's own side wall), 01b vs 02b by 526.82mm³ (4 regions, the same
class), and 04a/04b vs 01a by a smaller but real 3.07mm³.

**Root cause: not the geometry alone — the interference check's own pair
list.** `generate_parts.py`'s assembly-interference suite reported
27/27 pairs at 0.000mm³, every run, for seven rounds. That list was
hand-written, and it never once included a face plate against its own
back shell — the exact pair that just failed on a real bed. A check that
reports "N/N pass" is only as trustworthy as its own pair list; a
hand-written list can silently omit an entire pair *class* and nothing
catches it, because nothing asserts the list itself is complete.

**Fix, four parts:**

1. **`FIT_CLEARANCE = 0.4mm`** — a new, named, real printing-allowance
   constant (PLA on a Bambu A1 prints slightly oversized — elephant
   foot, extrusion width — so a 0.0mm nominal fit is a 0.0mm real
   collision), used everywhere a boss/insert/plate NESTS or SLIDES into
   another part. This is a different constant from the pre-existing
   `FIT_CLR` (0.5mm, the display's own pocket clearance) — not reused,
   not confused with it.
2. **Perimeter bosses repositioned off a real clearance formula**, not
   the old "centre of the rim/gap/margin strip" (which never checked the
   boss's own OD against the shell's inner wall at all): `_PERIM_MARGIN
   = WALL + FIT_CLEARANCE + BOSS_OD/2`, applied to both `PERIM_A` (01a/
   02a) and `PERIM_B` (01b/02b). One `PERIM_A` position (`_PA_XR`) is
   ALSO closer to the real display than the wall — the standard 9mm
   `BOSS_OD` plus `FIT_CLEARANCE` on both sides needs 9.8mm of real
   space, and the true available space there is only ~8.3mm. Fixed the
   same way `03-screen-trim`'s own boss already does elsewhere in this
   build ("the ring's own border is narrow here"): a smaller,
   position-specific boss OD (`PERIM_BOSS_OD_TIGHT`, computed from the
   real available space, floored to 0.1mm, asserted to still clear
   `INSERT_WALL_MIN`), used only at that one position.
3. **The display's real edge, not a symmetric-centre guess.** The first
   attempt at fix #2 assumed the display's native STEP bbox is centred
   on its own placement origin (`SCREEN_CX ± DISP_H_NATIVE/2`) and
   patched the mismatch with a guessed 1.0mm margin — that guess was
   wrong (the real mismatch is ~2.9mm, not the ~0.55mm an earlier,
   stale estimate suggested), so the guess silently changed nothing
   at all between two full runs. Fixed by reading the display STEP's
   own real native bounding box once, early in the script (before any
   of the geometry that depends on it), and using its real
   `native_Y`-max directly — no guess, no margin to get wrong.
4. **`04a`/`04b` vs `01a`'s own `BAND_MOUNTS` boss** — `INSERT_Y0` was a
   fixed offset that never checked itself against the boss's own real
   tip; the insert's front face landed 0.1mm inside the boss's own tip.
   Fixed: `INSERT_Y0 = FACE_T + BAND_BOSS_LEN + FIT_CLEARANCE`, a real
   clearance off the boss's own actual geometry.

**The pair list itself, replaced.** `ALL_PLACED` now holds all 13 parts
+ 11 hardware proxies (24 items); every one of the resulting 276 pairs is
checked for real overlap (assert ≤0.5mm³, real numerical noise only) —
nothing is hand-picked or silently skipped. The one legitimate skip
(`04a` vs `04b`, interchangeable band-insert variants that are never both
installed at once) is in a named `SKIP_PAIRS` dict with its own reason
string, not just left out.

**A separate fit-clearance pass, because zero-distance touch isn't
always a defect.** 20 of the 276 pairs are genuine `INTENDED_CONTACT` —
flat seating faces (the face-plate/shell seam, module-to-module seams),
press fits (the gold tab, the wall-cleat hook), stacked hardware (the
Pi5 sitting directly behind the display) — allowed to measure ~0mm. The
other 255 are NESTING/SLIDING fits (a boss inside a wall, an insert into
a window) and must clear by `FIT_CLEARANCE` or the check fails loud,
by name, with the real distance. Before this round's fixes, 8 pairs sat
at exactly 0.000mm; 6 were legitimate `INTENDED_CONTACT` (now classified
as such), and the other 2 (`01a` and `03-screen-trim`, both vs the real
display) were genuine defects, fixed as described above and in the item
below.

**Flagged for sign-off, not silently patched:** `03-screen-trim`'s own 4
mounting bosses ALL touch the real display at 0.000mm — and unlike the
perimeter bosses, this isn't an X/Z placement problem with an escape
route. `TRIM_MOUNTS` sits at the display's own active-area corners,
which fall within the display module's real footprint everywhere on
this build, and the display's real front face sits only 3.5mm off 01a's
own front (`DISPLAY_Y_FRONT = FACE_T + FIT_CLR`), leaving ~3.1mm of real
room behind the trim ring for a boss — well under the 7.1mm a full
`INSERT_DEPTH`=6.5mm M3 heat-set insert needs, at ANY position within the
ring's own footprint. No boss reposition or resize fixes a depth
shortfall this size. Fixed by changing 03's own fastener at these 4
mounts from an M3 heat-set insert to a self-tapping screw straight into
a shortened, capped boss (`trim_boss_len` capped to the real available
depth minus `FIT_CLEARANCE`; `TRIM_PILOT_D=2.6mm` pilot, sized for a
real M3 self-tap in PLA) — a legitimate, common real-world fix for a
light, low-load decorative bezel ring (unlike the structural perimeter
case screws), but a genuine fastener-spec change, **not just a geometry
nudge** — needs the coordinator's own sign-off, not a silent "improvement."

**Minor stringing at the wash-LED channel, column module (plate 3) —
identified, chamfer attempted and reverted.** `bed_face_scan()` already
reports (doesn't fail) a real bridge at this channel's own near
(cavity-side) mouth on `02b` — span 7.5mm, under the 10mm guideline, at
the SAME sharp 90° lip where solid wall material resumes right above
the channel's open void. That sharp lip is a real, known stringing
cause even under the span guideline (nothing for the extrusion to land
on but a hard step) — this is what DJ saw. A real FreeCAD edge chamfer
was tried on this exact edge (found by a geometric predicate, not a
fragile edge index) and **made things worse**: it turned the same
region from an `[OK]` bridge into a hard-FAIL cantilever, because the
new bevel face's own downward-facing area reads to `bed_face_scan()`'s
own classifier as an 80mm-long, one-side-supported region — a bigger
defect than the one being fixed. Reverted rather than shipped broken,
matching round 7's own precedent (a rib fix that also made things worse
was reverted there, not forced through). Making the classifier
recognise a chamfer bevel as "supported" is a real check-logic change,
not a 1-line nudge, and wasn't safe to improvise under this round's own
don't-regress-the-build rule. Left as bare geometry, reported here for
a human call: either accept the cosmetic stringing (it's real but
minor, per DJ's own report), or revisit with the check's own logic
in scope, not just this one channel's geometry.

**Result, confirmed by direct re-run:** `generate_parts.py` passes every
check — 0 `[FAIL]` lines, all 13 parts solids=1/valid=True/shells=1,
overlap 0 pairs over 0.5mm³ across 275 checked pairs (1 named-skip), and
every one of the 255 nesting/sliding pairs clears by ≥0.4mm.
`python3 bambu/build_project.py` exits 0, all 9 plates slice with zero
warnings.

## Print-orientation checks (round 4/4b — for context)

A packaging pass built the real Bambu Studio project (`bambu/build_project.py`)
and sliced every plate for real (A1, 0.20mm Standard, supports OFF). That
found two parts that didn't actually sit flat the way this README claimed,
and real slicing found a third, different problem class on top:

1. **01b's 24-detent ribs were raised 0.6mm.** Printed "front face down,"
   the part stood on the ~108mm² tick ring alone, with the rest of the
   face floating 0.6mm. **Fixed:** the ticks are now ENGRAVED (recessed
   ~0.6mm into the front) instead of raised, so the front is one flat
   plane at Y=0. Same 24 ticks, same readability, one boolean sign
   flipped (`cut` instead of `fuse`).
2. **02b's mic-cradle shelf (and its two side lips) started 1mm forward
   of the rim plane.** Printed "open-front down," the part stood on that
   1mm-proud shelf/lips, floating the actual rim 1mm off the bed.
   **Fixed:** pulled back to start exactly at the rim plane (`y0`), with
   the far end held at its original absolute position so the mic
   assembly's own real clearance is unchanged.
3. **The wall-cleat's documented orientation ("back face down") was
   wrong from this part's very first version.** Its wedge cut removes
   most of that face — at H=13.8/D=11.8 it's only `H-D=2mm` tall, ~33%
   real contact. Its actual best face (also what Bambu Studio's own
   "most-contact" auto-orientation finds independently) is its
   ORIGINAL bottom face (Z=0, never touched by the wedge cut) — i.e.
   **no rotation at all**. **Corrected** in `PRINT_ORIENTATIONS` and in
   this table.
4. **Real slicing found a fourth, different defect class 1-3 don't
   cover: internal fused features that hang off a wall into open
   cavity air with a flat leading cap and nothing underneath** — "It
   seems object 02a-back-shell-screen has floating cantilever," later
   "floating regions" on both 02a and 02b. Found and fixed for real:
   - **Speaker-pod tube (02a):** started abruptly at full 50mm OD,
     12mm above the rim, with nothing below it. **Fixed** with a real
     45°-safe conical lead-in (grows from the shoulder bore's own
     radius, i.e. zero wall thickness, up to full OD over ~6mm).
   - **KY-040 anti-rotation tab (02b):** same pattern, ~43mm above the
     rim. **Fixed** with a 45°-safe wedge taper at its leading edge
     (the functional PCB-stop face, at the back of the rib, is
     unchanged).
   - **Amp + level-shifter mounts and the band-LED channel:**
     redesigned from fused PROUD rings/troughs (the same floating
     pattern, just rectangular) to **RECESSED POCKETS cut into the
     back wall's own existing material** — a pocket in a wall that's
     already there isn't a new unsupported structure, same reasoning
     as 01a's own screen-trim front rebate.

### Two checks added, real and asserted, not just described

- **`print_orientation_check()`** (flat/plate-like parts: 01a, 01b, 03,
  04a, 04b, 05, 06, 07, 08, 11) — rotates the part into its stated
  orientation, sits it on the bed, and requires ≥80% of its own real
  footprint to be in the first 0.3mm layer (80%, not 100%, so a small,
  individually-verified-safe shallow feature like 01a's own trim
  rebate — real wall support on both sides, confirmed by real slicing
  to need no support — doesn't false-fail a check whose actual target,
  "no feature stands proud and props up the rest," is about the
  <1%-contact pattern the original raised ribs/shelf actually showed).
- **`overhang_scan()`** (tub/shell parts: 02a, 02b) — the footprint
  metric doesn't apply to a tub (only the rim is *meant* to touch the
  bed); this scans every downward-facing planar face steeper than 45°
  from vertical and not on the bed, and reports three tiers rather than
  forcing one pass/fail number it can't actually justify by geometry
  alone (see the function's own docstring): the whole-panel back-wall
  bridge (reported as an **open, unresolved item** — see below), the
  pocket-scale faces from fix #4 above (reported, not asserted — this
  scan can't tell a pocket floor from a cantilever cap by face geometry
  alone), and small residuals (the back-cup mounting bosses' own
  leading caps, ~33mm² each — a real 45° taper doesn't fit there
  without shrinking the M3 insert's own 6.5mm real thread depth, so
  it's documented and left, not silently papered over). The scan's own
  hard assert fires only on anything OUTSIDE those three named,
  explained tiers.

```
PRINT_ROTATIONS (axis, angle-deg) -- printed by generate_parts.py, for a
packaging script to reuse directly:
  '01a-face-plate-screen':      axis=(1,0,0), angle=90.00deg
  '01b-face-plate-column':      axis=(1,0,0), angle=90.00deg
  '02a-back-shell-screen':      axis=(1,0,0), angle=90.00deg
  '02b-back-shell-column':      axis=(1,0,0), angle=90.00deg
  '03-screen-trim':              axis=(1,0,0), angle=90.00deg
  '04a-band-insert-ignition':    axis=(1,0,0), angle=90.00deg
  '04b-band-insert-nightfall':   axis=(1,0,0), angle=90.00deg
  '05-band-diffuser':            axis=(1,0,0), angle=90.00deg
  '06-knob':                     axis=(1,0,0), angle=90.00deg
  '07-gold-tab':                 axis=(1,0,0), angle=90.00deg
  '08-speaker-back-cup':         axis=(1,0,0), angle=90.00deg
  '11-wall-cleat':                axis=(0,0,1), angle=0.00deg   (no rotation)
```

### Resolved in round 5 — see "Round 5" above

The open item that used to live in this section (`bambu/build_project.py`
exiting 1 on "floating regions"/"floating cantilever" for 02a/02b) was
**fixed, not papered over**, by the coordinator's own root-cause call:
the problem was print ORIENTATION, not a missing support rib. See
"Round 5 — cleat rail split off, 02a/02b flipped to back-wall-DOWN"
above for the full fix (the cleat-receiver rail split, the orientation
flip, and the two new defects the flip itself exposed). Confirmed by a
real re-slice, not just this script's own checks: `python3
bambu/build_project.py` now exits 0, every plate, zero warnings.

Every file: **support-free** in its stated orientation, one solid, no
enclosed voids, confirmed against the real slicer. Estimated print time
is now available too — see the per-plate times in "Round 5" or the
build's own console output.

## Assembly order

1. **02a (screen back-shell):** heat-set the perimeter-mount inserts (in
   01a — see below), the display-retention path needs no insert of ours
   (see "Display retention"). Fit the display+Pi5+Active-Cooler module
   into the cavity through the open front; drive 4× M3 from the true
   exterior back wall, through the real display's own captured
   enclosure-mount holes (RPi's own hardware provides the thread — this
   design only provides clearance). Drop the MAX98357A amp and the
   74AHCT125 level-shifter into their respective friction trays. Press
   the 40mm speaker into the pod's shoulder from the front (through the
   band opening, before the insert/diffuser go on) and screw the
   back-cup (08) on from the true exterior back, 4× M3, sealing the
   30–60cc back chamber.
2. **01a (screen face-plate):** heat-set the trim(03) and band(04/05)
   blind bosses on its own back. Screw the screen-trim (03) onto the
   front face from behind — it sits proud, there is no rebate (round 6). Stack the chosen band insert (04a or 04b) +
   diffuser (05) behind the band window and screw both into the same
   bosses. Lay the WS2812B strip in the band-LED trough and the
   perimeter LED strip in the wall-wash channel (both on 02a, both
   channels — the adhesive backing isn't doing structural work). Screw
   01a onto 02a's open front — 6× M3, driven from the true exterior back
   wall, spanning the open cavity into 01a's own blind bosses (this is
   what hides every fastener from the finished front).
3. **02b (column back-shell):** heat-set the seam bosses (left wall),
   perimeter-mount bosses. Drop the USB mic dongle + its short USB-A
   extension into the cradle shelf under the top wall, feeding the
   dongle's face up toward the 5 top-edge mic ports.
4. **01b (column face-plate):** mount the KY-040 encoder through the
   bushing hole from the front, secured by its own M7×0.75 nut (the
   nut IS the retention — no separate bracket). Snap the KCD1 rocker
   into its cutout from the front. Press-fit the gold tab (07) into its
   pocket. Screw 01b onto 02b (4× M3, same back-driven convention as
   step 2).
5. **Seam:** align 02a's right wall against 02b's left wall; drive 4× M3
   through 02a's clearance holes into 02b's blind bosses — this is what
   actually holds the two modules together edge-to-edge.
6. Press the knob (06) onto the KY-040's D-shaft.
7. **Cleat rail (12) — NEW, round 5:** heat-set the rail's own 3× M3
   inserts. Screw the rail onto 02a's back wall BEFORE hanging — from
   inside the cavity (i.e. before step 1's own 01a-onto-02a screw-down,
   or through the same clearance holes any time before the panel goes
   on the wall), so the fastener is never visible once assembled or
   hung. The rail's own registration recess self-jigs its position; no
   separate alignment step needed.
8. Screw the wall-cleat (11) to studs/drywall anchors; hang the assembled
   panel by the rail (12) — the two 45° faces engage and the panel's own
   weight wedges them together. Verified in the assembly reference at a
   real 16.8mm engagement depth with a 0.252mm face gap, 02a+rail's own
   back-most point, 02b's own back, and the cleat's own rear face all
   coplanar at `BACK_PLANE_Y` (see "Wall-cleat engagement" under
   Verification); the wall-to-front-face distance once hung is 66.56mm.

## Verification

Every check below is a real boolean operation on the actual exported STEP
geometry, not a description of intent — see `generate_parts.py`'s own
`export_and_verify()` / `probe()` / `interfere()` helpers.

### Per-part topology (solids / valid / shells / bbox)

| Part | Solids | Valid | Shells | Bounding box (mm) |
|---|---|---|---|---|
| 01a-face-plate-screen | 1 | True | 1 | 219.32 × 10.10 × 200.24 |
| 01b-face-plate-column | 1 | True | 1 | 90.00 × 10.10 × 200.24 |
| 02a-back-shell-screen | 1 | True | 1 | 219.32 × 51.56 × 200.24 |
| 02b-back-shell-column | 1 | True | 1 | 90.00 × 63.56 × 200.24 |
| 03-screen-trim | 1 | True | 1 | 175.76 × 4.60 × 107.30 |
| 04a-band-insert-ignition | 1 | True | 1 | 185.32 × 2.00 × 39.00 |
| 04b-band-insert-nightfall | 1 | True | 1 | 185.32 × 2.00 × 39.00 |
| 05-band-diffuser | 1 | True | 1 | 185.32 × 1.00 × 39.00 |
| 06-knob | 1 | True | 1 | 30.00 × 18.00 × 30.00 |
| 07-gold-tab | 1 | True | 1 | 13.70 × 1.50 × 5.70 |
| 08-speaker-back-cup | 1 | True | 1 | 56.00 × 6.00 × 56.00 |
| 11-wall-cleat | 1 | True | 1 | 180.00 × 11.90 × 13.90 |
| 12-cleat-receiver-rail | 1 | True | 1 | 160.00 × 12.50 × 12.00 |

02a's own Y dimension dropped from 63.56mm to 51.56mm this round —
expected, not a regression: the 12mm ridge that used to be fused in
(reaching `BACK_PLANE_Y`) is now the separate rail (12), so 02a's own
bare bounding box is just its real depth (`PANEL_D`, plus a hair of
back-wall margin) again.

03-screen-trim's own Y dimension dropped from 8.60mm to 4.60mm in round
8 — expected, not a regression: its own mounting boss is now capped to
the real space available before the display's own front face (see
"Round 8" above), shorter than the standard `BOSS_LEN_MIN` every other
insert boss in this build uses.

All 13 files: solid count == 1 (asserted inline — fails loud on
regression), `isValid() == True`, exactly 1 shell per solid (no enclosed
internal voids), and every file fits the 250×210×210mm bed in some
axis-aligned orientation (`fits_bed()`, checked against the bed's 3
*distinct* axis limits, not a naive 250mm cube assumption). Parts with a
fixed nominal footprint additionally assert `envelope_xy` (nothing sticks
out past the part's own outer skin, on the two axes that matter for that
part) — all confirmed flush.

### Feature-exists probes (31 run, 31 passed)

Every declared opening, cast as a real probe solid intersected with the
actual exported part:

| Feature | Result |
|---|---|
| 01a screen window | 0.00% blocked (fully open) |
| 01a band window | 0.00% blocked |
| 01b dial bushing hole | 0.00% blocked |
| 01b rocker cutout | 0.00% blocked |
| 01b gold-tab pocket itself | 0.00% blocked (open, as it should be) |
| 01b gold-tab pocket floor | 100.00% blocked (genuinely BLIND, not a through-hole) |
| 02a cable slot | 0.00% blocked |
| 02a speaker acoustic bore | 0.24% blocked (real shoulder ring, expected) |
| 02a display-retention holes ×4 | 0.00% blocked, each |
| 02a Active-Cooler vents ×4 | 0.00% blocked, each |
| 02b mic ports ×5 | 0.00% blocked, each |
| 04a/04b mount holes ×4 each | 0.00% blocked, each, probed at the insert's own real Y position |
| amp board footprint (in its tray) | 0.00% blocked |
| mic extension+dongle footprint (in its cradle) | 0.00% blocked |

### No-unintended-openings ray grid

| Plate | Grid | Open points | Undeclared-open |
|---|---|---|---|
| 01a-face-plate-screen | 55×50 | 1229 | **0** |
| 01b-face-plate-column | 23×50 | 22 | **0** |

Every see-through point on both face-plates lies inside a declared opening
(screen window, band window, dial bushing hole, rocker cutout, or the
trim's own 4 mounting clearance holes — added to the declared list after
the first run correctly flagged it as undeclared).

### Assembly interference (round 8: ALL pairs, exhaustively — see "Round 8" below)

**Superseded, round 8.** The hand-written 27-pair list below was real but
incomplete by construction — it never included a face plate against its
own shell, which is exactly the pair DJ's real prints found colliding.
Replaced with an exhaustive all-pairs check: every placed part + hardware
proxy against every other (276 pairs from 24 placed items, 1 named-skip
for the interchangeable 04a/04b band-insert variants), asserted at
≤0.5mm³ overlap, with a separate fit-clearance pass (below) — see "Round
8" for the full story. The old table is kept for its own historical
record of what round 6/7 actually checked at the time:

Real Raspberry Pi Touch Display 2 STEP, transformed to its actual installed
world position via a real rotation matrix (derived, not hand-waved — see
`generate_parts.py`'s docstring for the full derivation, and the sanity
check that the transform's active-area centre matches the value the
window cut itself used), plus envelope boxes for the Pi5+Active-Cooler
stack, DSI cable-bend reserve, KY-040 module+wires, rocker body+wiring,
the installed speaker, and every perimeter/seam screw's own full swept
length — checked against the real exported shell geometry:

| Pair | Result |
|---|---|
| Display (installed) vs 02a | 0.000mm³ |
| Pi5+Active-Cooler envelope vs 02a | 0.000mm³ |
| DSI cable-bend reserve (placeholder) vs 02a | 0.000mm³ |
| KY-040 module+wires vs 02b | 0.000mm³ |
| Rocker body+wiring vs 02b | 0.000mm³ |
| KY-040 envelope vs rocker envelope | 0.000mm³ |
| Speaker (installed) vs 02a | 0.000mm³ |
| Perimeter/seam screws (×20 total) vs Pi5/speaker/KY-040/rocker envelopes | 0.000mm³, every one |

**Mic-to-speaker real 3D distance: 218.7mm** (spec minimum 40mm — the two
components are in different modules entirely, so this was never going to
be close, but it's computed from the real installed centres, not assumed).

**Sealed speaker back-chamber volume: 32.9cc** (cup recess 11.3cc + pod
tube bore behind the driver 21.6cc) — within the BOM's 30–60cc target,
computed from the actual built geometry, not assumed.

**Chrome (screen-trim) share of the visible face: 6.9%** (4273mm² /
61938mm²) — well under the task's 20% cap.

### Fit-clearance check (round 8, new) — 24 placed items, 276 pairs

Separate from the overlap check above: real overlap (>0.5mm³) is always
a defect, but a real ZERO-distance touch is only sometimes one — flat
seating faces and press fits are SUPPOSED to touch. Every pair is
classified once, by name, not inferred from the numbers:

| Class | Count | Rule |
|---|---|---|
| `INTENDED_CONTACT` | 20 pairs | ~0mm allowed (seams, press fits, stacked hardware) |
| NESTING/SLIDING | 255 pairs | must clear by ≥`FIT_CLEARANCE` (0.4mm) or the check fails, by name |
| `SKIP_PAIRS` (named reason) | 1 pair | `04a` vs `04b` — interchangeable variants, never both installed |

Result, this run: 0 pairs over 0.5mm³ overlap; every nesting/sliding
pair clears by ≥0.4mm. See "Round 8" above for the 2 pairs that failed
this check before their fixes landed, and the fix for each.

### Sound-path check (new, revision 2) — driver axis through every band layer at once

The per-part probes above each check ONE part in isolation, which is
exactly why the original build shipped a speaker firing into solid
plastic without tripping any of them: 05-band-diffuser passed every
topology and probe check on its own (a plain 1mm sheet with 4 mount holes
is a perfectly valid solid), and the whole *stack* was never checked
together. Fixed with a real ray grid — a Ø38mm disk of probe rays, 2mm
grid spacing, fired along the driver's own firing axis, through
`01a-face-plate-screen`'s band window, whichever band insert is fitted,
and `05-band-diffuser` — all three in their real installed positions,
combined into one compound and tested as one boolean per ray, not three
separate per-part checks:

| Insert | Rays clear through all 3 layers | Result |
|---|---|---|
| 04a-band-insert-ignition | 80/276 (29.0%) | **OK** (≥25% minimum) |
| 04b-band-insert-nightfall | 76/276 (27.5%) | **OK** (≥25% minimum) |

Both variants clear the task's 25% minimum with real margin, computed
from the actual fitted geometry (window + insert + diffuser stacked),
not from any single part's own open-area percentage.

### Wall-cleat engagement (revision 3) — real, coplanar, not floating

**Three passes on this, each catching something the previous pass missed
— all from an independent geometry review,
not from any check that existed at the time:**

1. *Floating.* The original build placed the wall-cleat 28mm behind the
   back-shell at an arbitrary offset, with nothing showing it actually
   engages the integrated receiver ridge on 02a.
2. *Wrong-scale bulk collision.* Engaging it for real (translate so the
   cleat's own 45° hook face shares the receiver ridge's exact hypotenuse
   line, then rotate 180° about an axis lying in that shared plane so
   the two solids land on OPPOSITE sides of it — the actual geometric
   condition for two wedges to mate rather than collide) exposed that the
   cleat's own bar, sized generically (30×20mm) with no reference to the
   12mm-tall receiver it needed to mate with, put ~6572mm³ of its own
   bulk straight through the back-shell's flat wall around the ridge.
   Fixed by resizing the bar to the receiver's own scale (12×11mm).
3. *Wrong face called "the wall."* That fix computed a "wall plane" by a
   hand-derived formula and reported 55.02mm — but the coordinating
   session's own check of the real geometry found the cleat's actual
   REAR (wall-mounting) face at Y=66.02mm, meaning the hand formula had
   silently reported the FRONT (hook) face instead. Worse, at that
   engagement, 02a's own back-most point (its ridge tip, 66.56mm) and
   02b's own back-most point (its flat back wall, previously computed
   independently from its own mic-cradle depth stack, 66.30mm) were not
   even coplanar with EACH OTHER — 0.26mm apart — so a hung panel would
   rock on whichever module's back sat proud, and both stood 0.3–0.5mm
   *into* the wall plane the cleat actually implied.

**Fixed for real, all three at once**, with one shared constant instead
of three independent guesses:

- **`BACK_PLANE_Y`** — one constant (66.56mm), derived from the screen
  module's own real ridge-tip position (`PANEL_D + 12mm`), used to set
  **both** shells' own back-most point AND the engaged cleat's own rear
  face. `COLUMN_PANEL_D` (02b's own depth) is now set to `BACK_PLANE_Y`
  directly (raised from its own independently-computed 66.30mm), with
  its real mic-cradle-driven minimum (66.30mm) kept as an asserted floor,
  never silently shrunk below what the mic+extension stack needs.
- The cleat's own cross-section (`CLEAT_BODY_D`/`H`) is now **derived**,
  not chosen, from two simultaneous real requirements: the rear face
  must land exactly on `BACK_PLANE_Y`, and the front (hook) face must
  clear `PANEL_D` with a real 0.2mm margin (a first derivation, solving
  for the rear face alone, drove the bar 0.08mm into the flat back
  wall around the ridge — a real, if tiny, 28.58mm³ collision the
  interference check caught). Because the difference between the two
  faces equals `D` regardless of the engagement gap, fixing `D` from the
  front-margin requirement satisfies the rear-face requirement
  automatically — the real hook-face gap then falls out as a **derived,
  reported** number, not a value chosen to hit the tolerance.
- The "wall plane" is now read directly off the transformed shape's own
  `BoundBox`, never a hand-derived formula.

**Round 5 update:** the receiver ridge is now the separate rail (12),
bolted to 02a rather than fused into it (see "Round 5" above). The
engagement math itself didn't change (the rail reproduces the old
fused wedge's exact geometry/position), but the checks now measure
against the rail's own real, installed geometry (`rail_placed`)
instead of 02a's bare shell — which changed two numbers for the more
honest: with the ridge fused into the WHOLE flat back wall, the
measured hook-face gap had quietly been dominated by the wall's own
0.2mm front margin nearby, not the ridge/hook geometry the design
formula actually describes (0.199mm measured vs. a 0.247mm derived
target — never actually the same measurement). Isolating the rail
exposed the TRUE hook gap (0.324mm, over the 0.3mm tolerance) — fixed
by retuning `CLEAT_FRONT_MARGIN` (0.2mm → 0.1mm) and re-measuring
directly rather than re-deriving by hand a second time.

| Check | Result | Requirement |
|---|---|---|
| Cleat bulk vs 02a+rail+02b interference | **0.000mm³** | zero |
| Minimum distance, cleat hook face to receiver rail | **0.252mm** | ≤0.3mm (real contact) |
| Hook engagement depth (shorter of the two mating segments) | **16.8mm** | ≥8mm |
| Cleat rear (wall-mounting) face | world Y = **66.56mm** | == `BACK_PLANE_Y` |
| 02a bare-shell back-most point (YMax) | **54.56mm** | recessed, expected < `BACK_PLANE_Y` (the rail bridges the gap) |
| 02a+rail assembled back-most point | **66.56mm** | == `BACK_PLANE_Y` (±0.05mm) |
| 02b's own back-most point (YMax) | **66.56mm** | == `BACK_PLANE_Y` (±0.05mm) |
| 02a+rail / 02b coplanarity | **0.00mm apart** | ≤0.05mm |
| Every part (01a/01b/02a/02b/03/04b/05/11-engaged/12-rail) vs. a slab just behind `BACK_PLANE_Y` | **0.0000mm³, every one** | ~0 (nothing stands into the wall) |
| **Wall-to-front-face distance when hung** | **66.56mm** | == `BACK_PLANE_Y` |

The 66.56mm wall-to-face distance is real, not a target — it equals
`BACK_PLANE_Y` by construction: the wall plane is exactly where both
shells' own backs and the cleat's own rear face all meet. This is
noticeably deeper than the screen module's own nominal 54.56mm depth
because the receiver ridge (necessarily proud of the flat back wall, to
give the cleat something real to hook onto) is the part that actually
touches the wall, not the flat wall itself — the flat back wall sits
12mm short of the wall plane everywhere except at the ridge, which is
consistent with (and helps, not hinders) the concept's own "wall wash of
light" feature wanting a real air gap for the LEDs to spill onto the
wall.

### `assembly-reference.step`

A visual-reference compound of every part in its installed position
(11 solids), **explicitly excluding the Raspberry Pi display STEP** — that
file is RPi's own, not ours to redistribute (see the open-build defect
list's own "vendor STEP baked into an export" item). Verified by reading
it back and confirming its solid count matches the sum of the parts alone
(no extra geometry leaked in). Download the real display STEP from RPi's
own URL (in `generate_parts.py`'s docstring) to see it in place.

## Real defects found and fixed this build (same discipline as every prior build)

1. **24-detent ribs rotated about the wrong axis.** A first draft rotated
   the tick-ring ribs about Z (`Rotation(Vector(0,0,1), angle)`); since the
   dial lies in the face-plate's own X-Z plane, that left every rib at
   nearly the same Z and fused none of them to the plate — caught as 23
   disjoint solids by `export_and_verify()`, not by eyeballing. Fixed by
   rotating about Y (the face-plate's own normal) instead, and by
   re-deriving the rib's own local dimensions (radial extent on X, not Z).
2. **Perimeter mounting bosses landed inside the band window's own
   cutout.** A first draft's `LEFT_RIM`/`GAP1` (6mm) were sized only for
   the display/dial layout, not for a real 9mm-OD boss with real edge
   margin — the boss's own fuse target was inside the just-cut window,
   a real Gotcha #1 floating-boss defect (4, then 5, disjoint solids).
   Fixed by widening those rims to 11mm and moving the perimeter mounts
   onto dedicated vertical strips that are clear of every cutout for
   their entire height, by construction — not by trial-and-error offsets.
3. **The band window cut used the FULL band-zone footprint, not the
   bordered `BAND_WINDOW_W/H`.** This put the insert/diffuser mounting
   bosses (`BAND_MOUNTS`, inset from the zone's own edge) inside the
   resulting empty cutout — same Gotcha #1 symptom, different cause.
   Fixed by actually cutting the smaller, bordered window.
4. **A rotated cutter, pivoted exactly at the cleat ridge's own thin
   overlap boundary, cut away the whole overlap** and left the wedge
   floating disconnected (2 solids instead of 1) — a real instance of the
   skill doc's own "rotate about a pivot" gotcha, from the SUBTRACTIVE
   side this time (a box-minus-rotated-cutter), not the additive side.
   Fixed by building the wedge directly as a 2D wire/face, extruded — no
   cutter-vs-overlap interaction to get wrong.
5. **The integrated cleat receiver collided with the display's own real
   retention holes, then (after the first fix) with the Active-Cooler
   vent row.** Two sequential feature-exists probe failures (30% and then
   14.55% blocked instead of open), fixed by computing the cleat's real Z
   position from the display's own geometry (`DISPLAY_CZ + 20`) instead
   of a hand-picked "near the top" guess, with real margin against both.
6. **Mic ports were declared and PROBED, but never actually cut** in
   `build_back_shell_column()` — a first draft wrote the probe before the
   cut and never noticed the cut was missing until the probe (correctly)
   read 60% blocked instead of open. Exactly the defect class this
   studio's whole feature-exists-probe discipline exists to catch.
7. **`AMP_POCKET_W, AMP_POCKET_D, AMP_POCKET_H` were assigned in the wrong
   order** (22 went to "D", 12 went to "H") — feeding the smaller 12mm
   value into the amp tray's own footprint height where the real board's
   17.8mm height needed to fit. The board-footprint probe read 22%
   blocked (the probe, correctly sized to the real board, stuck 2.9mm
   into the tray's own ring wall on both sides) — not caught by any
   topology check, since the tray+shell fuse was already one valid solid
   regardless of which value went where. Fixed by correcting the
   assignment order and naming.
8. **The most serious defect this build: the band-insert perforation
   cuts, the diffuser's mount-hole cuts, and the insert's own mount-hole
   FEATURE-EXISTS PROBE all used a cutting-tool Y-span (`-2` to `+2..6`)
   copied from the face-plate's own "Y=0 is the front face" convention —
   but the insert/diffuser plates themselves sit much further back
   (Y≈10–17mm), so every one of those cuts (133+85 perforations, 4+4
   mount holes) was subtracting a tool that never touched the plate at
   all.** `plate.cut(tool)` "succeeded" — no exception, valid solid,
   correct bounding box, correct printed hole *count* from the loop
   counter — and the exported STEP was silently a **plain 6-face box**
   for all three parts. The feature-exists probe for the mount holes
   ALSO used the same wrong Y-span, so it read "0% blocked" and passed —
   **vacuously**, because it was probing empty space outside the part
   entirely, not a real hole. This is a genuinely new gotcha, not yet in
   the shared catalogue: **a cutting tool (or a verification probe) must
   be checked against the TARGET's own real Y-position, not assumed to
   share the Y=0-is-the-front-face convention every other part in the
   build happens to use** — a probe that "passes" by missing the part
   entirely is indistinguishable from a probe that passes for the right
   reason unless someone looks at the *absolute* face/solid count, which
   is exactly how this was actually caught (04a's exported STEP had 6
   faces where 143 were expected, found by direct inspection after the
   round STL byte-count looked suspiciously small for 133 declared
   holes). Fixed by giving every insert/diffuser cutter real reach
   (length 40mm from Y=-2, comfortably spanning the actual plate
   position) and by re-deriving the mount-hole probe's own Y-span from a
   new named `INSERT_Y0` constant instead of a copied literal.
   **Recommended addition to the shared skill doc's gotcha catalogue** —
   this is the same root failure mode as Gotcha #1/#2 (a boolean op
   "succeeds" on geometry that doesn't actually interact) but from a
   coordinate-frame mismatch rather than an overlap/bridge-width mistake,
   and it defeated a verification probe as well as the cut itself, which
   neither #1 nor #2 do.
9. **The speaker fired into 05-band-diffuser's own solid plastic, and both
   band inserts were too sparse over the driver to pass real sound even
   once that's fixed.** Found by an independent
   review of `assembly-reference.step`, not by any check that existed at
   the time — a light diffuser being fully solid, or a grille insert being
   5-15% open overall, breaks no topology rule and blocks no declared
   opening (the diffuser's own 4 mount holes were real and open; the
   insert's own perforations were real and open; per-part checks all
   passed). The defect only exists at the ASSEMBLED-STACK level: three
   independently-valid parts, stacked, that together don't let sound
   through. Fixed two ways: (a) `05-band-diffuser` now has a real
   Dia38mm acoustic opening over the driver's own firing axis, matching
   the cone, instead of being a plain unbroken sheet; (b) both band
   inserts now carry a real denser pattern specifically inside that same
   Dia38mm acoustic zone (ignition: a 3.5mm/5.5mm-pitch hex cluster,
   31.4% open there; nightfall: a dense star cluster in the same 3
   standard sizes weighted larger, 32.1% open there), both clearing the
   task's 25% minimum, while keeping each insert's own light-zone
   character (hex grid / sparse bottom-fading starfield) everywhere
   outside that zone. A new **sound-path check** (see "Verification"
   above) now fires a ray grid along the driver's own axis through all
   three layers stacked in their real installed positions at once —
   the class of check that would have caught this the first time, and
   that no single-part probe or interference check can substitute for.
10. **The wall-cleat, over three passes, floated, then collided, then
    engaged against the wrong face.** All three found by the coordinating
    session's own independent review, each only visible once the
    previous one was fixed:
    (a) *Floating* — the original build placed the wall-cleat 28mm
    behind the back-shell with no engagement shown at all.
    (b) *Wrong-scale bulk collision* — placed at its real engaged
    position (translate so its own 45° hook face shares the receiver's
    exact hypotenuse line, then rotate 180° about an axis lying IN that
    shared plane so the two wedges end up on OPPOSITE sides of it, the
    actual geometric condition for a mating contact rather than a
    collision — "put the lines on top of each other" with no flip was
    tried first and gave a same-side collision instead), its own bulk (a
    generic 30×20mm bar, sized with no reference to the 12mm-tall
    receiver it needed to mate with) plowed ~6572mm³ through the
    back-shell's flat back wall around the ridge. Fixed by resizing the
    bar to the receiver's own scale.
    (c) *Wrong face called "the wall," and the two modules' backs not
    coplanar with each other* — the resized engagement's own "wall
    plane" was computed by a hand-derived formula that reported the
    cleat's FRONT (hook) face as if it were the REAR (wall-mounting)
    face; an independent check of the real geometry
    found the actual rear face 11mm further out, and — worse — found
    02a's own back-most point (its ridge tip) and 02b's own back-most
    point (its flat back wall, computed independently from its own
    mic-cradle depth stack) were 0.26mm apart, so a hung panel would
    rock, with both shells standing 0.3-0.5mm *into* the actual wall
    plane. Fixed with one shared `BACK_PLANE_Y` constant (66.56mm,
    derived from the screen module's own real ridge-tip position) that
    now sets **both** shells' own back-most point AND the cleat's own
    rear face, plus a from-scratch re-derivation of the cleat's own
    cross-section from two simultaneous requirements (rear face on
    `BACK_PLANE_Y`, front face clearing `PANEL_D` with real margin) —
    fixing a naive single-requirement derivation that drove the bar
    0.08mm into the flat wall (a real 28.58mm³ collision the
    interference check caught) — and by reading the "wall plane" off the
    transformed shape's own `BoundBox` directly instead of a hand formula
    a second time. See "Wall-cleat engagement" under Verification above
    for the full numbers as they stood then (0.000mm³ interference,
    0.199mm contact gap, 16.7mm engagement depth, both shells and the
    cleat's rear face coplanar at 66.56mm) — and "Round 5" for how the
    receiver ridge later became its own part (12-cleat-receiver-rail),
    which changed the gap measurement to 0.252mm (see current table).

## What's real vs. estimated — full placeholder ledger

Per the task's own instruction: a parallel BOM-research pass
(`bom-research.md`, 2026-09-21) confirmed most of the electronics
dimensions below from real datasheets/manufacturer pages; what's still
genuinely unverified is flagged **PLACEHOLDER**.

| Dimension | Status | Source |
|---|---|---|
| Display bbox (189.32×120.24×14.96mm landscape), active area (157.76×89.30mm, +2.43mm offset), Pi5 standoffs (49×58mm, 8.5mm boss height), enclosure-mount holes (70.72×140.0mm) | **Real**, independently re-measured this build from the official STEP | RPi's own STEP (`RP-009154-DD-1`) |
| Active Cooler height (13.70mm bare) | **Real, cited** | RPi's own mechanical drawing |
| Active Cooler design clearance (16mm, not 13.70mm) | **BOM-corrected** | bom-research.md §2.3 |
| M3 heat-set insert hole (Ø4.0×6.5mm, was 5.7mm) | **BOM-corrected** | bom-research.md §2.14 (CNC Kitchen geometry) |
| KY-040 PCB (26.20×18.63mm), bushing M7×0.75, thread ~7mm, shaft Ø6×20mm | **BOM-verified** | bom-research.md §2.6 (components101/Joy-IT/DuPPa) |
| KY-040 shaft D-flat width (4.5mm) | **PLACEHOLDER — ASSUMED** | bom-research.md: "measure first articles" |
| KY-040 max panel thickness at the bushing (≤3mm) + local 2.0-2.5mm boss | **BOM-reasoned**, implemented as a 2.25mm local thinned zone | bom-research.md §2.6 |
| KCD1 rocker cutout (19.3×13.2mm), body-to-terminals (21.4mm), clearance reserve (≥30mm) | **BOM-corrected** | bom-research.md §2.8 (HandsOn KCD1-102 drawing) |
| KCD1 local panel thickness for snap clips (1.5mm) | **PLACEHOLDER — ASSUMED** | bom-research.md: "not stated on the drawing" |
| Speaker frame OD (41mm, not the nominal 40mm), depth (21mm), no mounting ears, open back needing a real sealed chamber | **BOM-corrected** | bom-research.md §2.10 |
| Speaker sealed back-chamber real target (30-60cc) | **BOM target, met** (32.9cc, computed) | bom-research.md §2.10 |
| MAX98357A board (19.4×17.8×3.0mm) | **Real** | Adafruit #3006 product page |
| MAX98357A mounting-hole spacing | **Not used** — mounted in a friction tray instead, per BOM's own "no reliance on holes" (clone boards vary) | bom-research.md §2.9 |
| USB mic dongle (22.2×18.3×7.0mm incl. plug) | **BOM-corrected** (was task's own ~18×10×5 estimate) | bom-research.md §2.11 (Adafruit #3367; SunFounder assumed equal) |
| USB extension female-end overmold (20×12×45mm pocket) + 2ft cable coil reserve (40×30×15mm) | **BOM-provided**, drives the column module's own extra depth | bom-research.md §2.12-2.13 |
| WS2812B strip: ~12 LEDs behind the band, ~40 around the perimeter (partial loop, not a full ~65-LED loop) | **BOM-provided target**, channels built to fit a partial loop; exact achieved LED count per channel not separately computed this pass — **open item** | bom-research.md §2.13 |
| 74AHCT125 level-shifter pocket (25×20×12mm) | **BOM-provided** | bom-research.md §2.13 |
| DSI FPC cable-bend reserve envelope | **PLACEHOLDER — my own margin**, not a datasheet figure | — |
| Pi5 USB-C cable slot (16×10mm, real margin over BOM's 14×9mm) | **BOM-informed**, positioned generically (not to the exact 11.2mm-from-edge port location) | bom-research.md §2.1/2.4 |
| Chrome bezel border width (8mm), rim/gap/margin widths (11mm on mount-bearing edges) | **My own engineering choice** | — |
| Band-insert perforation hole sizes/pitch (both variants) | **My own engineering choice** | — |
| Cleat wedge dimensions, receiver position | **My own engineering choice** | — |
| `FIT_CLEARANCE` (0.4mm, round 8) | **My own engineering choice**, a real PLA-on-A1 printing allowance, not a datasheet figure — distinct from the pre-existing `FIT_CLR` (0.5mm, the display's own pocket clearance) | — |
| `TRIM_PILOT_D` (2.6mm self-tap pilot, round 8) | **PLACEHOLDER — reasoned, not measured**: a common real-world M3-self-tap-in-PLA pilot size (~85-90% of the screw's major diameter), not pulled from a specific screw's own datasheet — verify against the actual self-tapping screw once bought | — |

## Design decisions / deviations from the concept sheet, with reasons

- **A visible vertical seam between the screen and the control column.**
  The concept sheet draws one continuous front face; this build has a
  real butt-line where 01a meets 01b. This is a genuine visual change
  from the concept, not a cosmetic afterthought, and it's forced, not
  chosen: 189.32mm (the real landscape display) + 62mm (the real
  24-detent dial ring's own minimum clear width) = 251.32mm, already over
  the 250mm bed limit with every rim/gap margin at zero. There is no
  version of this panel, at this hardware's real size, that prints as one
  piece on this bed — see "Why this is two modules" below for the full
  arithmetic. The seam sits in the same place the concept sheet's own
  front elevation already draws a visual break (the control column is
  drawn as a distinct inset rect with its own border), so the split
  follows an existing seam in the concept's own composition rather than
  cutting across it arbitrarily — but it is still a real, visible line on
  the finished object that the original single-panel concept doesn't
  have, and should be called out as such rather than absorbed silently.
- **Two bolt-together modules, not one panel.** See "Why this is two
  modules" above — a hard bed-width constraint, not a style choice.
- **Column module is deeper than the screen module (66.56mm vs
  54.56mm).** A real, BOM-driven consequence of the mic+USB-extension
  stack's own real length — flagged, not silently absorbed into a forced
  uniform depth.
- **Mic ports are on the TOP EDGE (through the back-shell's own top
  wall), not the front face**, unlike a literal reading of the concept
  sheet's front-elevation drawing (which shows them as small front-view
  circles near the top of the column). This matches the task's own text
  ("mic ports on the top edge") and keeps the front face genuinely clean
  — the concept sheet's own front-view circles are the conventional way
  these sketches draw a top-edge feature in elevation, not a literal
  front-face opening.
- **Screen-trim mounts in a FRONT rebate, not a blind back boss.** A
  first draft (before this was caught) put the trim's mounting bosses on
  the panel's own back, which would have pulled a front-*visible* bezel
  ring to the *back* of the panel instead of seating it flush in front —
  fixed to a real front rebate + through-clearance-hole-from-behind
  design, which is both correct and still satisfies "fixed from behind."
- **Amp and level-shifter mount in friction trays, not screw holes** —
  BOM's own explicit finding that clone MAX98357A boards vary in
  hole presence/spacing.
- **Speaker mounts by clamping its rim (a shoulder step), not screw
  ears** — BOM's own finding that open-frame 40mm drivers have neither.
- **The band is split into one real acoustic zone (Ø38mm, over the
  driver) and light zones everywhere else**, rather than treating the
  whole band as one uniform perforation pattern. This is a real design
  change from revision 1, made after an independent review
  found the speaker firing into solid diffuser plastic — see "Real
  defects" #9. Both variants keep their own light-zone character (hex
  grid for ignition, sparse bottom-fading starfield for nightfall)
  outside the acoustic disk, and get a genuinely denser pattern (still
  matching each variant's own visual language) inside it.
- **Gold tab is a static press-fit, not a mechanical reveal** — the
  task's own documented, explicit deviation from the xxx5 style guide's
  "mechanical reveal" convention for this element; not something this
  build introduced.
- **LED wall-wash is a partial loop** (bottom + both side edges of each
  module's own back wall), not a full perimeter loop — matches the
  BOM's own "~40 LEDs implies a partial loop, not the ~65 a full loop of
  this size would need" finding. Achieved channel length not separately
  measured against the ~40-LED target this pass — open item.
- **Wash channel does not run along the very top edge** — the top edge
  hosts the mic ports and (on the screen module) the integrated cleat
  receiver; extending the wash channel there was judged not worth the
  added risk this pass, so the wash loop is 3 of 4 sides per module, not 4.

## Open before anything here is printed or published

1. **Print all 12 files** (both band-insert variants, at least once each)
   and test-fit the real display, Pi 5 + Active Cooler, KY-040, KCD1
   rocker, 40mm speaker, MAX98357A, USB mic + extension, and WS2812B
   strips. Nothing here has touched a bed yet.
2. **Confirm the KY-040 shaft D-flat width (4.5mm assumed)** and the
   KCD1 snap-clip panel thickness (1.5mm assumed) against the actual
   parts once bought — both flagged PLACEHOLDER above.
3. **Slice and record real print times** — not computed this pass.
4. **Measure the achieved wall-wash LED run length** against the BOM's
   own ~40-LED partial-loop target; add more channel if short.
5. **Licence:** design files are CC-BY-4.0, code Apache-2.0 (see ../LICENSE).
6. **Public name:** "Dial Panel" is the working name.

## Files

```
generate_parts.py                          -- this build's full source
print_rotations.json                       -- print orientation per part, data (name -> axis/angle_deg),
                                               written by generate_parts.py from PRINT_ROTATIONS; the
                                               single source of truth bambu/build_project.py reads
bom-research.md                            -- the BOM agent's dimension research (read first)
step/*.step                                -- every part's STEP, incl. 12-cleat-receiver-rail (round 5)
out/common/*.step, *.stl                   -- every shared part (01a,01b,02a,02b,03,05,06,07,08,11,12)
                                               + 04a/04b (both variants, for reference/editing)
                                               + assembly-reference.step (no Pi display STEP)
out/ignition/04a-band-insert-ignition.stl  -- "Ignition" team release STL
out/nightfall/04b-band-insert-nightfall.stl -- "Nightfall" team release STL
```

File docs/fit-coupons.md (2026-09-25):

# Fit coupons

Three small test pieces, cut straight out of the real printed parts, so you
can check the fits that have actually gone wrong on this build **without**
printing the full plates 1, 2 and 3 (10 h 36 m combined on a Bambu Lab A1).
Print `bambu/dial-panel-coupons.3mf` instead — two plates, about 1 h 25 m
total — before you commit a full print run to a body part you haven't
fitted yet.

**These are test pieces, not printed parts of the finished panel.** They
don't go in the assembly. Throw them away (or keep them as a fit-check kit)
once the real plates have printed and fitted.

## Why coupons instead of a smaller scale model

If you've built one of these before, printing a 25% scale model to check
fit quickly is the obvious move — except it doesn't work here. Every
failure this build has actually had came from a clearance that was too
tight, and clearances don't scale: shrink the whole part to 25% and
`FIT_CLEARANCE` (0.4 mm) becomes 0.10 mm, the wall thickness (3.0 mm)
becomes 0.75 mm, and the M3 clearance hole (Ø3.4 mm) becomes Ø0.85 mm — well
under what any FDM printer can resolve reliably, and nowhere near what a
real M3 screw needs. A quarter-scale model would tell you the *shape* is
right and say nothing true about whether it *fits*, which is the one
question these coupons exist to answer.

A coupon fixes this by staying at 1:1 and being cut, not redrawn, from the
exact STEP files that ship in `cad/step/` — the same geometry that goes to
the real plates. If a coupon fits, the real part fits that spot. If a
coupon doesn't, the real part won't either, and you've found out in about
85 minutes instead of 10+ hours.

## What "cut from the real part" means

Each coupon is a small box, intersected with the actual exported part —
never a fresh sketch of what that corner is *supposed* to look like. Where
two parts meet (a screw boss and the wall it sits inside; the two halves
of the seam), both halves are cut with the exact same box, so the
interface between them survives the cut exactly as it is in the real
parts. Regenerate all three any time the real parts change:

```
freecadcmd cad/coupons.py
python3 bambu/build_coupons_project.py
```

## The three coupons

### A — Screen corner (`A1` + `A2`)

**Tests:** a perimeter screw boss nested right up against the shell's own
side wall, right at a corner — the tightest clearance spot on the whole
panel. `A1` is the face-plate corner (`01a`, with its screw boss); `A2` is
the matching back-shell corner (`02a`, with the wall it has to clear).

**This is the fault that cost plates 1, 2 and 3 the first time** (2026-09-22
log entry, "the screw base bumps the edge of the body"): the perimeter
bosses overlapped their shell's wall by up to 2 mm, so the two halves
physically could not close. `A1`/`A2` are cut at the single tightest boss
on the whole panel — the one narrow enough that this build gives it its
own smaller boss diameter (`PERIM_BOSS_OD_TIGHT`) instead of the standard
one, because there isn't room for the standard size there.

**Pass:** press `A1`'s boss into `A2`'s wall opening by hand. It should
seat flush with a firm push, no sanding, no visible gap. A washer or the
flat of an M3 screw head should sit flat against the boss face once seated.

**Fail:** the boss won't seat, or seats only after removing material —
meaning the real face plate and shell won't close either, and you should
hold off printing plates 1 and 2 until the CAD is adjusted (and this coupon
reprinted and re-checked) rather than find out after a 10-hour print.

### B — Column seam (`B1` + `B2` + `B3`)

**Tests:** two faults at once, both from the fix that shipped as PR #12 —
the seam bolt's own path and bore, and a perimeter screw that used to run
straight into the seam's internal support rib. `B1` is the back shell,
column half (`02b`); `B2` is the face plate, column half (`01b`); `B3` is a
matching strip cut from the screen-side back shell (`02a`), carrying the
other half of the seam bolt holes.

**This is the fault found on 2026-09-24**, right after plate 3 was
reprinted for the *first* fix and finally seated: three of the four column
screws ran straight into the seam's own support boss/rib block (measured
at the time as 49.5 mm of solid material blocking the screw), and — a
separate, worse problem found while fixing that — **all four seam bolt
holes were completely filled in**, with no bore at all, so the two modules
could not be bolted together no matter what. Both faults are inside this
one coupon.

**Pass:** thread an M3 screw through `B2`'s perimeter hole into `B1`'s
boss — it should turn freely all the way to the boss, no resistance
partway in (that resistance is exactly what "running into the rib"
felt like on the real print). Separately, pass an M3 bolt through `B3`'s
clearance hole and into `B1`'s seam boss — it should also thread in
freely, and you should be able to see daylight through the bore from the
back before you do (the bore existing at all was the second fault).

**Fail:** either screw binds, stalls, or won't start — meaning the real
column module has the same fault, and printing plate 3 (or the screen
module's plate 2, for the seam bore) again would be reprinting a known bad
fit.

### C — Band mount (`C1` + `C2` + `C3`)

**Tests:** the clamped stack that holds the backlit band together — one
M3 screw through the diffuser, then the insert, then into a boss on the
face plate, with all three meant to sit flush with **zero** gap, not just
close. `C1` is the face-plate corner with the boss (`01a`); `C2` is the
matching corner of the ignition-variant band insert (`04a`); `C3` is the
matching corner of the band diffuser (`05`).

**This is the fault found on 2026-09-23**: the band insert and diffuser
originally had no working mounting features at all. The four mounting
holes landed 1.0 mm outside the parts' own outline (so the "hole" removed
0.00 mm³ — just a corner nick, not a hole), and even once holes existed,
the insert floated 0.4 mm behind the boss it bolted to and the diffuser a
further 1.0 mm behind that — a screw could only bow the stack, not clamp
it.

**Pass:** stack `C3` on `C2` on `C1` (diffuser, then insert, then face
plate, in that order — this is a "one screw through everything" test, not
three loose fits) and drive one M3 screw through all three. The stack
should pull down flat with normal screw torque — no visible gap between
any two layers, and the screw shouldn't bottom out or spin freely before
the stack is tight.

**Fail:** a gap remains between any two layers even at full screw
tightness, or the screw doesn't reach thread in the boss — meaning the
real band assembly (plates 7, 8/9) has the same problem, and the insert or
diffuser needs another CAD pass before reprinting them.
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

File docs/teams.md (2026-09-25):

# Choosing a team

One release, two looks. Pick one **when you build** — a Dial Panel keeps its
team for life. Body, trim, dial and gold are identical; only the light changes.

| | **A · IGNITION** | **B · NIGHTFALL** |
|---|---|---|
| It's… | a sunrise | a starfield |
| Band insert | `stl/ignition/04a-band-insert-ignition.stl` — ember perforation | `stl/nightfall/04b-band-insert-nightfall.stl` — starfield perforation |
| Screen | banded sun on a warm grid | stars over a cyan grid on deep violet |
| LED light | torch `#FF7A1A`, warm | violet `#7B2FF7` (grid light cyan `#22E8E0`) |
| Suits | an entryway or kitchen: it greets you | a hallway or living room at night |
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

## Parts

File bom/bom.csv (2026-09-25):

line | part | spec | qty_per_build | cart_qty | amazon_title_checked | amazon_url | cart_price_usd | pack_size | per_build_usd | status | notes
1 | Raspberry Pi 5 (4 GB) | BCM2712 SC1111 | 1 | 1 | TRASKIT Basic kit for Raspberry Pi 5 4GB RAM, 27W PD Power Supply, PI5 Case, Active Cooler | https://www.amazon.com/dp/B0G4R8TSLN | 158.64 | 1 | 158.64 | in stock 2026-09-21 | Board-only listing B0CK3L9WD3 out of stock. Kit PSU/cooler probably not official parts; the case is unused. Alternative: CanaKit Essentials 4GB B0CVQTWGBX $189.99, or PiShop.us board $110.
2 | Raspberry Pi Touch Display 2 (7 in) | 720x1280 DSI 5-point touch SC1635 | 1 | 1 | Raspberry Pi Touch Display 2, 7-inch LCD Screen, 720 x 1280 | https://www.amazon.com/dp/B0DM24QFCF | 90.00 | 1 | 90.00 | third-party seller (marked up) | Includes both FPC cables (incl. Pi 5 standard-to-mini), power leads and 8 M2.5 screws. List $60; PiShop.us $81.95.
3 | Raspberry Pi Active Cooler | official PWM blower | 1 | 0 | (in the Pi kit) | https://www.amazon.com/dp/B0CLXZBR5P | 10.00 | 1 | 0.00 | in kit | Standalone official-branded listing shown; only needed if not using the kit.
4 | Raspberry Pi 27 W USB-C PSU (US) | 5.1 V 5 A PD | 1 | 0 | (in the Pi kit) | https://www.amazon.com/dp/B0D3MFLNC1 | 23.41 | 1 | 0.00 | in kit | Use a STRAIGHT USB-C plug; the enclosure has a slot for it. Do not use a right-angle adapter (5 A mode).
5 | microSD card | 64 GB A1 | 1 | 1 | SANDISK 64GB Ultra microSD ... A1 | https://www.amazon.com/dp/B0B7NXBM6P | 23.99 | 1 | 23.99 | in stock | Any 32 GB+ A1/A2 card works.
6 | KY-040 rotary encoder module | EC11 with push switch; 6 mm D-shaft; M7x0.75 bushing | 1 | 1 | Taiss 5Pcs KY-040 Rotary Encoder Module | https://www.amazon.com/dp/B07F26CT6B | 8.99 | 5 | 1.80 | in stock | Buy the D-flat shaft variant. Wire + to 3.3 V only. The printed knob replaces the included cap.
7 | Mini rocker switch | KCD1-101 2-pin SPST ON-OFF snap-in 21x15 | 1 | 1 | Rocker Switch 2 PIN ON-Off SPST ... KCD1-101 (Pack of 10) | https://www.amazon.com/dp/B08683RMVY | 10.89 | 10 | 1.09 | in stock | The mic cut: breaks the USB mic's VBUS.
8 | I2S amplifier | MAX98357A breakout 3 W @ 4 ohm | 1 | 1 | 2PCS MAX98357 MAX98357A I2S 3W Class D Amplifier Breakout | https://www.amazon.com/dp/B0DPJRLMDJ | 6.88 | 2 | 3.44 | in stock | Headers need soldering (or use a pre-soldered variant).
9 | Speaker | 40 mm 4 ohm full-range open frame | 1 | 1 | Gikfun 4Ohm 40mm Diameter 3W Full Range Audio Speaker (Pack of 2) EK1794 | https://www.amazon.com/dp/B01LN8ONG4 | 8.99 | 2 | 4.50 | in stock | No mounting ears; clamped by the printed ring into a printed sealed back-cup.
10 | USB microphone | USB audio class mini mic (driverless) | 1 | 1 | SunFounder USB 2.0 Mini Microphone for Raspberry Pi | https://www.amazon.com/dp/B01KLRBHGM | 7.99 | 1 | 7.99 | in stock | Plug-and-play on Raspberry Pi OS.
11 | USB-A extension (to splice) | USB 2.0 A male to A female ~60 cm | 1 | 1 | 3 Pack USB Extension Cable 2 FT ... Male to Female | https://www.amazon.com/dp/B0CDC3KQN1 | 8.99 | 3 | 3.00 | in stock | Cut the red VBUS wire and route it through the rocker. Coil the spare length in the back shell.
12 | WS2812B LED strip | 5 V 60 LED/m 10 mm IP30 adhesive | 52 LEDs (2 x 1 m) | 2 | BTF-LIGHTING WS2812B IC RGB LED Strip ... 60LED IP30 | https://www.amazon.com/dp/B01CDTED80 | 17.98 | 60 LEDs per strip | 7.79 | in stock | 12 behind the band + ~40 wall-wash. Cap brightness ~25% (Pi 5 V budget).
13 | Level shifter (recommended) | 74AHCT125 quad 3V to 5V | 1 | 1 | Adafruit 74AHCT125 - Quad Level-Shifter [ADA1787] | https://www.amazon.com/dp/B00XW2L39K | 7.25 | 1 | 7.25 | in stock | DIP-14 on a scrap of perfboard (soldering). Many strips run on 3.3 V data without it: try first; add it if the LEDs flicker.
14 | M3 heat-set inserts | M3 x 5.7 L x 4.6 OD (fits a 4.0 mm hole) | ~16 | 1 | 140Pcs M3 Heat Set Threaded Insert M3x5.7x4.6mm | https://www.amazon.com/dp/B0DDWS7BTS | 6.99 | 140 | 0.60 | in stock | Avoid generic M3x5x4 kits: wrong geometry for the holes.
15 | M3 socket-head screws | M3 x 6-16 mm assortment | ~16 | 1 | 780PCS M3 Hex Socket Screw Assortment Kit | https://www.amazon.com/dp/B0GRV5NW7Q | 9.99 | 780 | 0.50 | in stock | fix/perimeter-screw-joint: seam bolts now M3 x 12 (was M3 x 16 -- the old length bottomed out 3.8mm proud against the seam boss's own blind base; this assortment already covers 12mm). Trim ring is NO LONGER in this line -- see 15b, it needs a shorter screw than this kit stocks.
15b | M3 self-tapping screws (short) | M3 x 3 mm self-tap | 4 | 1 | not yet sourced -- shortest common length is not in the M3 x 6-16mm assortment above |  |  |  |  | not researched | fix/perimeter-screw-joint: trim ring (03) mounting boss is a shallow self-tap (no heat-set insert -- see docs/assembly.md step 1), real usable pilot depth ~2.9mm. M3 x 3 gives 3.0mm engagement, ~0.1mm over that pilot depth -- flagged as a real but small miss (self-tap screws commonly advance slightly past a nominal pre-drilled pilot by cutting fresh thread; not asserted as risk-free). If a genuinely shorter/tighter fit is wanted, the fix belongs in 03-screen-trim's own boss/pilot depth (cad/generate_parts.py), which is a real geometry change outside this branch's scope (SEAM/TRIM were doc+BOM only this round).
16 | Dupont jumper wires | F-F (kit incl. M-F/M-M) | ~15 | 1 | ELEGOO 120pcs Multicolored Dupont Wire | https://www.amazon.com/dp/B01EV70C78 | 6.98 | 120 | 0.90 | in stock
17 | Heat-shrink assortment | 2:1 mixed | a few | 1 | Ginsco 580 pcs 2:1 Heat Shrink Tubing Kit | https://www.amazon.com/dp/B01MFA3OFA | 7.99 | 580 | 0.25 | in stock | For the VBUS splice.
18 | Wall screws + anchors | 2 x wood screw ~#8 x 1.5 in + drywall anchors | 2 | 0 | (any hardware store) |  |  |  |  | not researched | For the printed french cleat.
F1 | Filament: matte black PLA | 1.75 mm 1 kg | ~450-600 g | 1 | Polymaker Panchroma Matte PLA ... Charcoal Black | https://www.amazon.com/dp/B0D7ZYCVTY | 16.99 | 1 kg | 8.50 | in stock | Body: face plate + back shell + band insert + cleat. Grams refined from the CAD.
F2 | Filament: silver silk PLA | 1.75 mm 1 kg | ~50-100 g | 1 | ELEGOO PLA Filament Silk Silver Grey 1KG | https://www.amazon.com/dp/B0C6QFDQWT | 15.99 | 1 kg | 1.30 | in stock | The "chrome": screen trim + knob.
F3 | Filament: yellow/gold PLA | 1.75 mm 1 kg | ~5-20 g | 1 | SUNLU PLA ... Yellow 1KG | https://www.amazon.com/dp/B0B12W69HT | 17.99 | 1 kg | 0.70 | in stock | The gold tab (a sample coil is plenty).
F4 | Filament: clear/natural PETG | 1.75 mm 1 kg | ~30-60 g | 1 | SUNLU PETG Filament ... Transparent | https://www.amazon.com/dp/B085TGGV3L | 16.99 | 1 kg | 0.85 | in stock | Band diffuser.

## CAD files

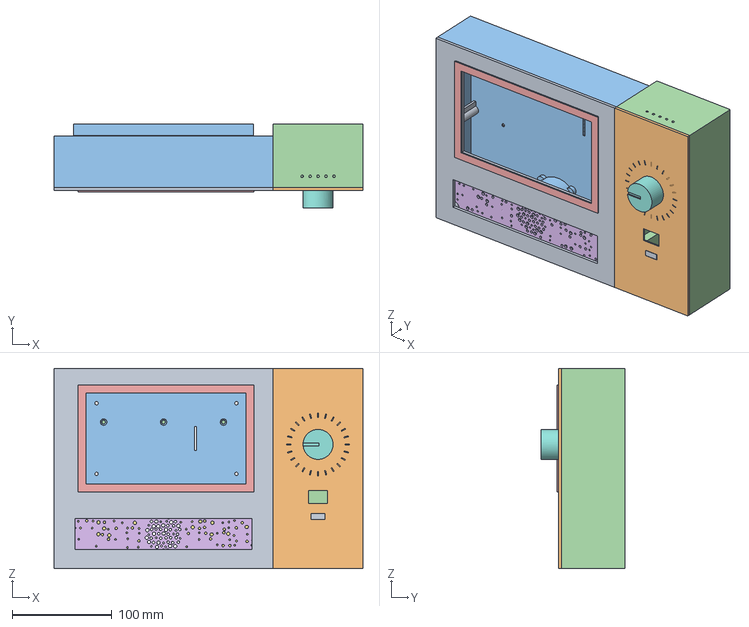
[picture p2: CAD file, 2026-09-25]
cad/step/assembly-reference.step
309.3 x 84.6 x 200.2 mm

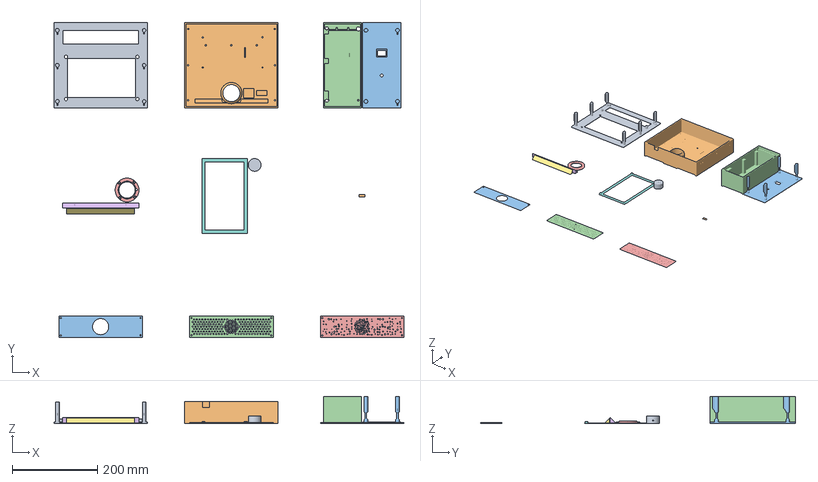
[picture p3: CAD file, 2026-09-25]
bambu/dial-panel-hw-2015.3mf
822.4 x 739.7 x 63.6 mm
01a-face-plate-screen
02a-back-shell-screen
01b-face-plate-column
02b-back-shell-column
08-speaker-back-cup
11-wall-cleat
12-cleat-receiver-rail
03-screen-trim
06-knob
07-gold-tab
05-band-diffuser
04a-band-insert-ignition
04b-band-insert-nightfall

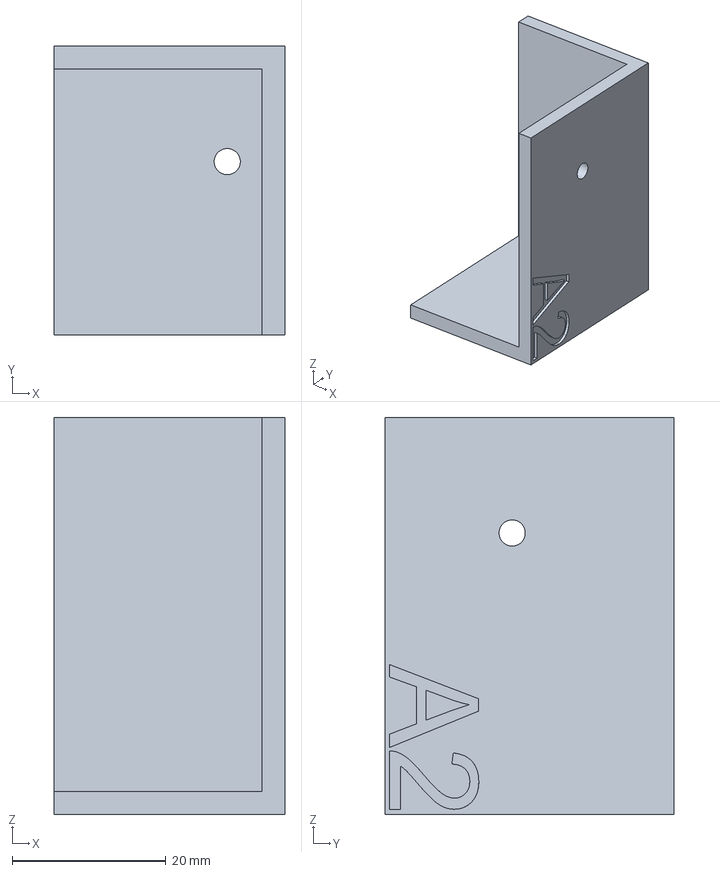
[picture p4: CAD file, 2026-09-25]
cad/coupons/A2-back-shell-screen-corner.step
30.0 x 37.5 x 51.6 mm

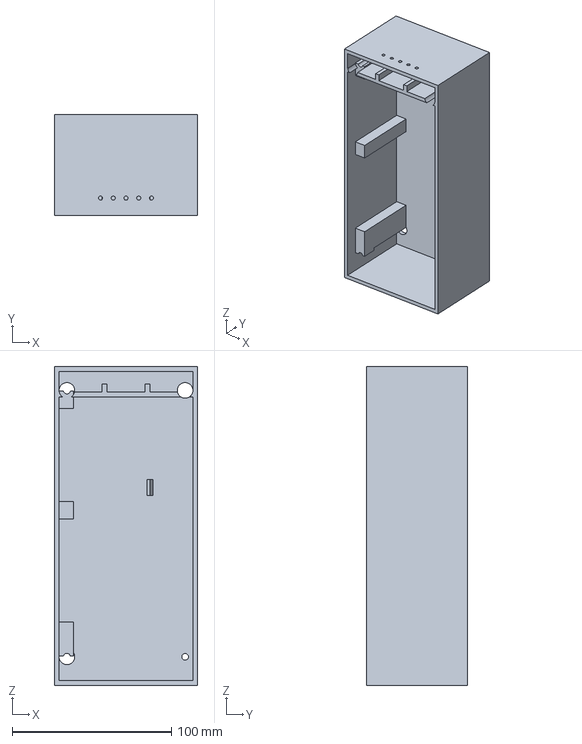
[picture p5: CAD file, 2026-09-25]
cad/step/02b-back-shell-column.step
90.0 x 63.6 x 200.2 mm

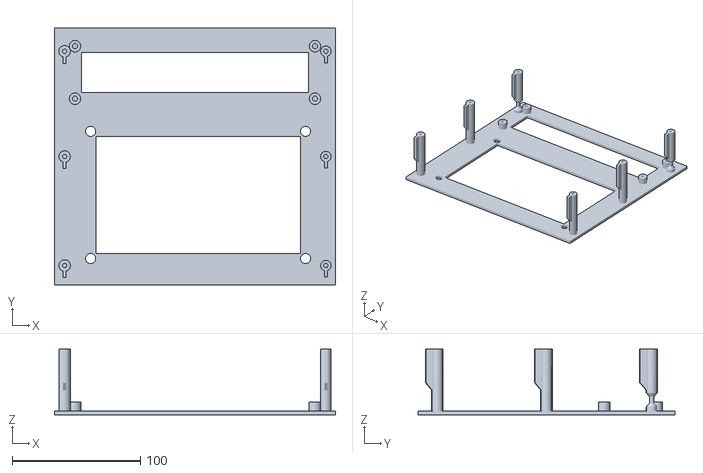
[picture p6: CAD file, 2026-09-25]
stl/common/01a-face-plate-screen.stl
219.3 x 200.2 x 51.2

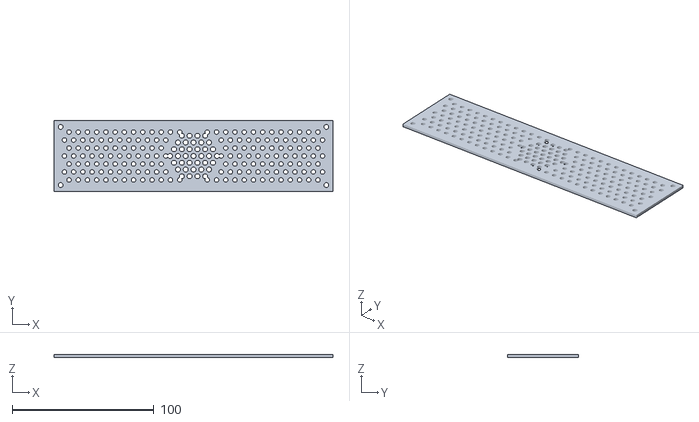
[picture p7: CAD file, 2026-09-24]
stl/ignition/04a-band-insert-ignition.stl
196.7 x 50.4 x 2.00

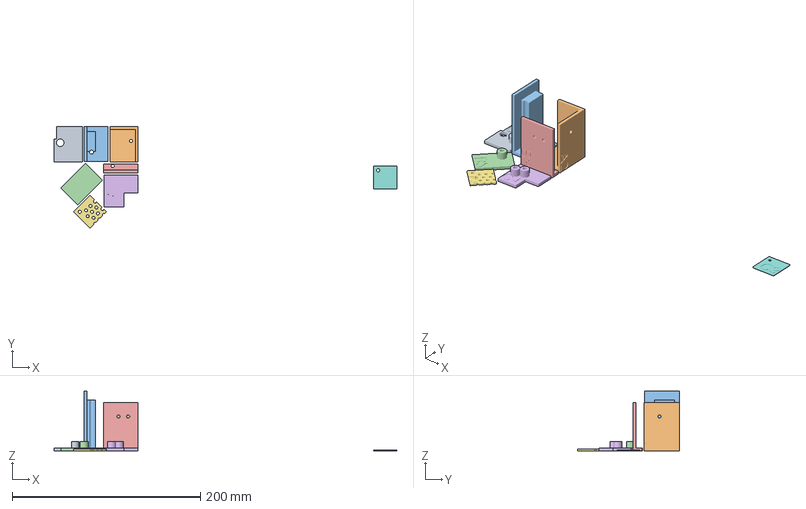
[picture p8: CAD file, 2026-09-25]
bambu/dial-panel-coupons.3mf
364.2 x 107.8 x 63.6 mm
A1-face-plate-screen-corner
A2-back-shell-screen-corner
B1-back-shell-column-seam
B2-face-plate-column-seam
B3-back-shell-screen-seam-strip
C1-face-plate-screen-band-mount
C2-band-insert-ignition-band-mount
C3-band-diffuser-band-mount

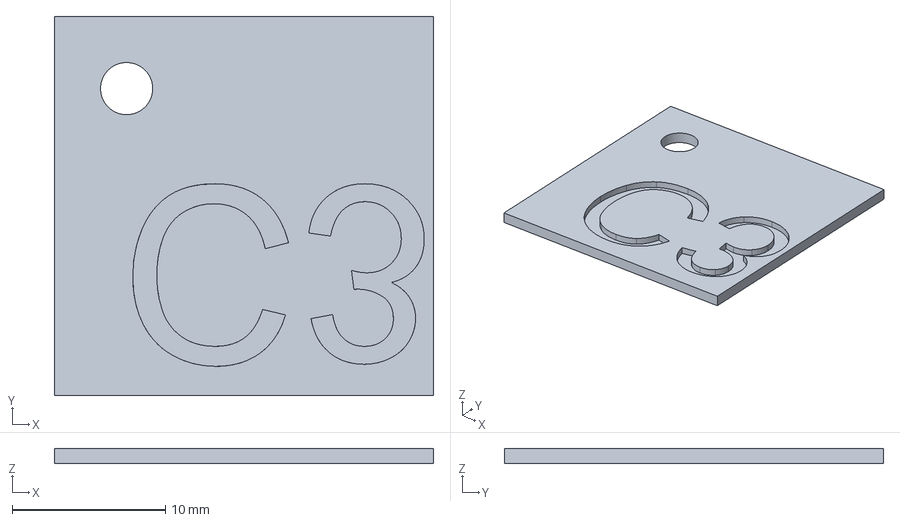
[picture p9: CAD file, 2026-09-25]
cad/coupons/C3-band-diffuser-band-mount.step
24.7 x 24.7 x 1 mm

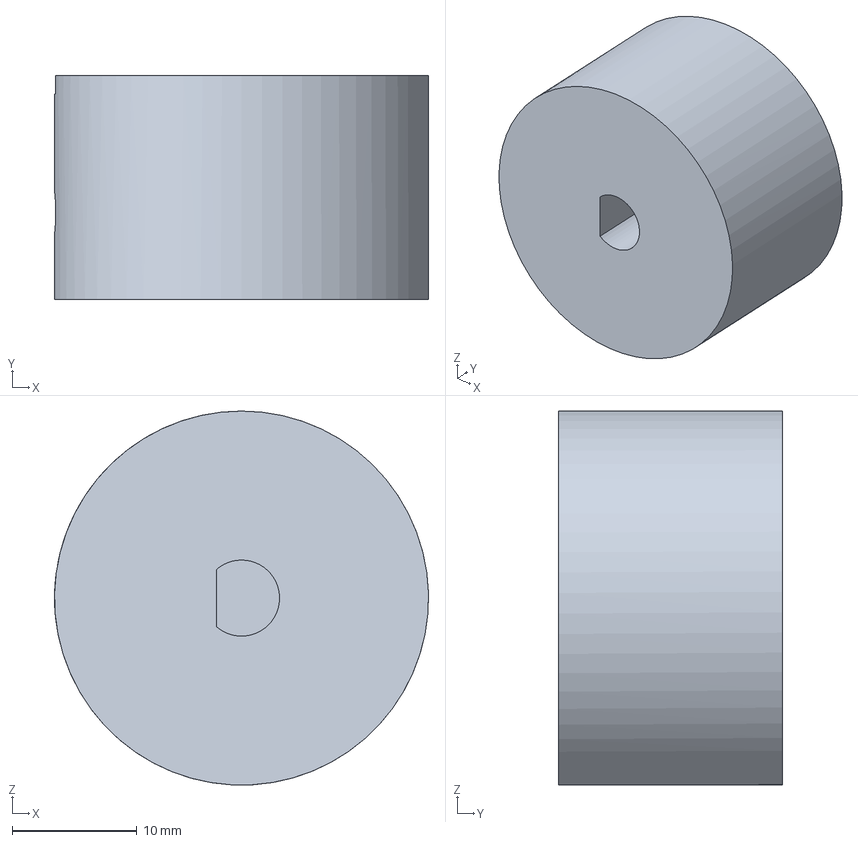
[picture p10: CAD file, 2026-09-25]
cad/step/06-knob.step
30.0 x 18.0 x 30.0 mm

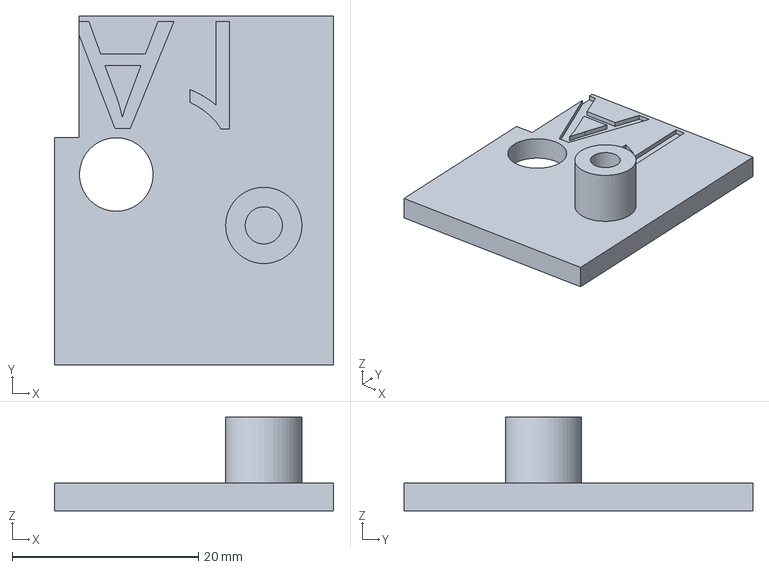
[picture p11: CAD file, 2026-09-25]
cad/coupons/A1-face-plate-screen-corner.step
30.0 x 37.5 x 10.1 mm

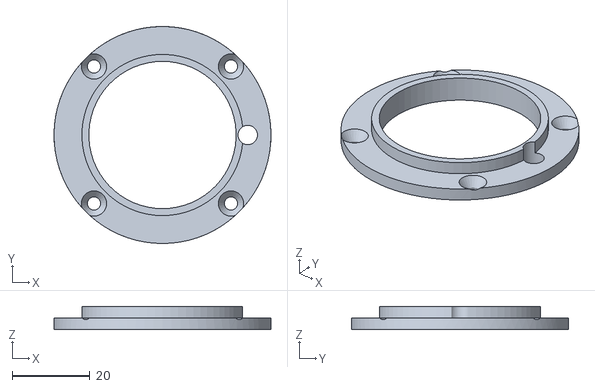
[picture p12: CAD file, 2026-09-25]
stl/common/08-speaker-back-cup.stl
56.0 x 56.0 x 6.00

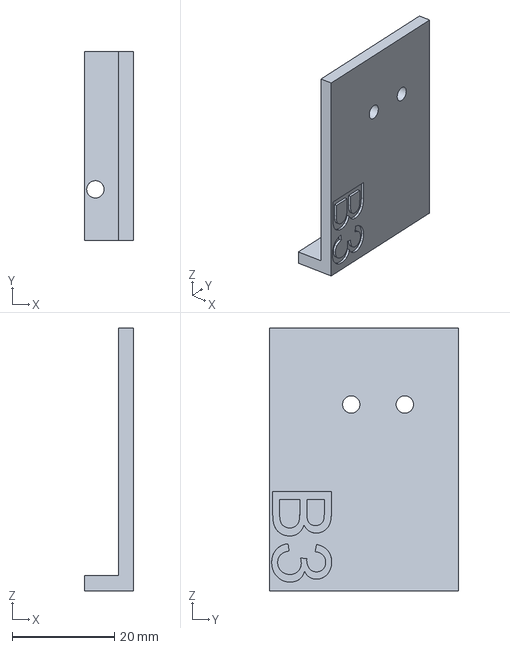
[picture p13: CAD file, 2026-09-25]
cad/coupons/B3-back-shell-screen-seam-strip.step
9.66 x 37.0 x 51.6 mm

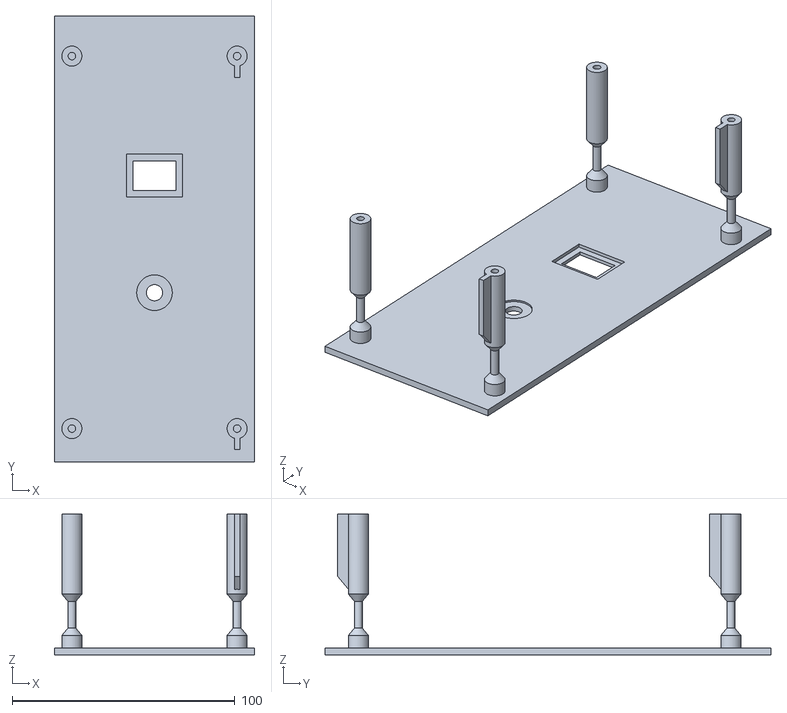
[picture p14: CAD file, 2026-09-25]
stl/common/01b-face-plate-column.stl
90.0 x 200.2 x 63.2

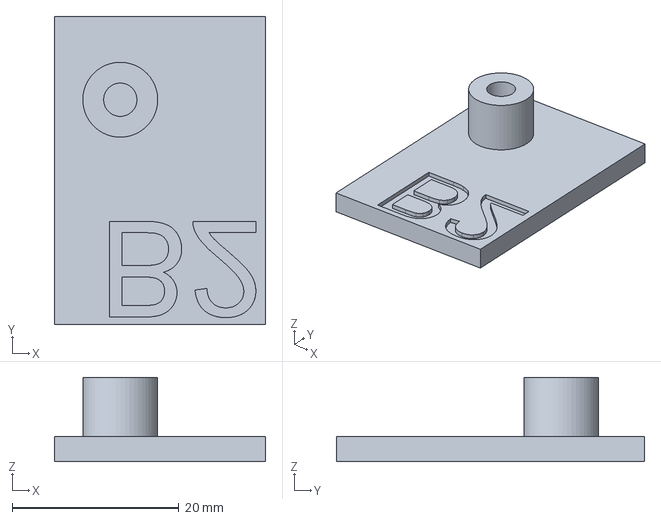
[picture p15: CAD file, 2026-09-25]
cad/coupons/B2-face-plate-column-seam.step
25.3 x 37.0 x 10.1 mm

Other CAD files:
stl/nightfall/04b-band-insert-nightfall.stl
stl/common/02b-back-shell-column.stl
cad/step/04a-band-insert-ignition.step
cad/step/04b-band-insert-nightfall.step
cad/coupons/B1-back-shell-column-seam.step
cad/coupons/C1-face-plate-screen-band-mount.step
cad/coupons/C2-band-insert-ignition-band-mount.step
cad/step/01a-face-plate-screen.step
cad/step/01b-face-plate-column.step
cad/step/02a-back-shell-screen.step
cad/step/03-screen-trim.step
cad/step/05-band-diffuser.step
cad/step/07-gold-tab.step
cad/step/08-speaker-back-cup.step
cad/step/11-wall-cleat.step
cad/step/12-cleat-receiver-rail.step
stl/common/02a-back-shell-screen.stl
stl/common/03-screen-trim.stl
stl/common/05-band-diffuser.stl
stl/common/06-knob.stl
stl/common/07-gold-tab.stl
stl/common/11-wall-cleat.stl
stl/common/12-cleat-receiver-rail.stl
stl/coupons/A1-face-plate-screen-corner.stl
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

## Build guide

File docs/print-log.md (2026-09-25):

# Print log

Real prints, what they showed, and what changed because of them. Add yours:
printer, filament, plate, what fit and what didn't. Fit reports are the most
useful contribution this project can get right now.

## 2026-09-22 · first prints · Bambu Lab A1, 0.20 mm, matte black PLA, supports off

### Plate 1 · 01a face plate — FAILED, fixed
Good overall, but the recessed lip around the screen window left **stringing
and deformed edges**.

**Cause.** That recess was the seat for the silver trim ring, cut into the
front face. 01a prints front-face down, so the recess was a pocket in the bed
face, and its ledge printed over air. Bambu's slicer did not warn, and the
first-layer check passed it at 84.5%.

**Fixed** (`1e4215f`): the rebate is gone, the front is one flat plane, and
first-layer contact is 100%. The trim ring now sits on top, proud by 1.5 mm,
still fastened from behind.

### Plate 2 · 02a back shell — printed on the pre-fix design, as predicted
Printed before the fix landed. **Stringing on the bottom edge at the cable
slot opening**, exactly where the new check reported a 16 mm unsupported
ledge (at z = 47.6 mm, about 4 mm below the top of the part).

**Fixed** (`1e4215f`): the cable slot now runs to the front rim, so there is
no ledge. The same commit splits the band-LED channel's 44 mm ceiling into
segments of 10 mm or less with gussets.

Still usable if you already printed it: both are print-quality defects in
those two spots, not fit or function.

### What these two taught the project
A slicer warning is not proof a part prints cleanly, and neither is a
first-layer contact percentage. `cad/generate_parts.py` now checks every part
for downward-facing surfaces with only air beneath them: anything spanning
more than 10 mm fails the build, shorter spans are reported with numbers. It
is proven against the old geometry — it flags the exact ledge that failed.

### Plate 3 · 01b + 02b, and the assembly that followed — FAILED to seat, fixed
Plate 3 printed with minor stringing at the light opening on the bottom.
Then **neither face plate would seat into its shell**: "the screw base bumps
the edge of the body."

**Printing plate 3 is how this was found**, and it condemned plates 1, 2 and 3
together — the same boss geometry is wrong on the screen module and the column,
so the parts already printed from plates 1 and 2 were stale the moment plate 3
came off the bed.

**Cause, measured in the CAD:** the face plates' perimeter screw bosses
genuinely overlapped the shells' side walls — 448 mm³ on the screen module
(6 bosses, 2 mm into each wall) and 527 mm³ on the column (4 bosses, two of
them ~9 mm deep). Not a tolerance problem: the parts intersected.

**Why no check caught it:** the interference list was written by hand and
**never paired a face plate with its own shell**. It checked the display, the
pod, the cleat and the screws against the shells, but not the two biggest
parts that bolt together.

**Fixed:**
- the overlap is gone, and every nesting fit now clears by a real 0.4 mm
  printing allowance (PLA prints slightly oversized; a nominal 0 mm fit
  means "does not fit")
- the interference check is now generated from **all pairs** of placed parts
  (276 pairs, 1 named skip: the two interchangeable band inserts), so a pair
  cannot be missed by forgetting it
- a separate fit-clearance check classifies each pair: intended contact
  (seating faces, the knob and gold-tab press fits, the cleat hook) may touch
  at ~0; anything that nests or slides must clear by 0.4 mm

**Reprint after this fix:** 01a face plate, 02a back shell, 02b back shell,
03 screen trim. **01b (column face plate), the knob, gold tab, speaker cup,
cleat, rail and both band inserts are unchanged** — parts already printed
are still good.

## 2026-09-23 · Bambu Lab A1, 0.20 mm, matte black PLA, supports off

### Plates 8 and 9 · both band inserts — printed clean
Plate 8 (IGNITION, `04a`) and plate 9 (NIGHTFALL, `04b`) both printed with no
defects. The perforated grille came out well at 0.20 mm.

**They still have to be reprinted** — not because of print quality, but
because of what fitting them revealed.

### The band insert and diffuser had no mounting features at all — FAILED, fixed
First fit of the diffuser against the face plate showed it would not go into
the band window. It was never going to: the parts are meant to sit *behind*
the window and overlap its edge, and the window is 177.5 × 30.5 mm while the
parts were 185.32 × 39.00 mm.

The real fault was underneath that. **Nothing held them in place.**

**Measured in the exported CAD:**
- All four mounting bosses sat **exactly 1.0 mm outside the parts' outline**,
  in both axes. So the four M3 clearance holes did not exist — the cut removed
  **0.00 mm³**, leaving a 0.29 mm nick in each corner instead of a hole.
- The insert floated **0.4 mm behind** the boss tips it was bolted to, and the
  diffuser a further 1.0 mm behind that, across open air. A screw could only
  bow them.
- The diffuser's nearest neighbour in any direction was **3.4 mm away**. It
  was unlocated in X, Y and Z.

Meanwhile the assembly doc told builders to "screw both into the same bosses,
4 × M3 × 8" — which was impossible as drawn.

**Cause.** An earlier round widened the window border to stop those same
bosses printing in mid-air. The insert and diffuser are *sized off that
window*, and were never re-derived, so the fix moved one reference and broke
the other. Same root cause as the plate-3 seating failure: **a number moved
and everything derived from it stayed put.**

**Fixed:** the overlap is now computed from the border rather than restated,
giving a 3.0 mm wall around every hole. The parts grow from 185.32 × 39.00 to
**196.72 × 50.40 mm**, the insert seats flush on the boss tips and the
diffuser flush on the insert — both gaps now 0.0000 mm. M3 × 8 still reaches,
with 5.0 mm of thread engagement, so no BOM change.

**A second defect the first fix created**, caught before printing: once the
inserts grew, NIGHTFALL's perforation pattern ran into two of its own screw
holes, leaving walls of **0.08 mm and 0.96 mm**. At a 0.4 mm nozzle that
prints as a merged slot and tears on the first turn of a screw. Perforations
are now suppressed within 2.0 mm of any mounting hole, in both variants.

**Three new checks**, each proven to fail on the old geometry first:
- **fastener-hole-exists** — compares the volume a hole boolean actually
  removed against the cylinder it was asked for. A hole that removes 0.00 mm³
  is now the loudest failure in the run.
- **clamped-stack contact** — bolted faces must touch, not float.
- **no floating part** — nothing may have a nearest neighbour greater than zero.
- **minimum feature wall** — measured on the *finished* part, every pair of
  holes, because the first check deliberately probes the reference outline and
  so cannot see material eaten away from the side.

That last pair is worth understanding if you contribute CAD here: one check
proves the hole is there, the other proves there is still material around it.
Neither one is sufficient alone.

**Reprint after this fix:** `04a` band insert (plate 8), `04b` band insert
(plate 9), `05` band diffuser (plate 7). **Every other part is geometrically
identical to the previous version** — verified part by part against volume and
bounding box, not assumed. All nine plates slice with no warnings.

Two known cosmetic notes, both pre-existing and both flagged rather than
silently exempted: 04a has two grille perforations that merge by 0.35 mm where
the sparse outer grid meets the dense acoustic cluster (present in the version
that printed clean above, so it is proven printable), and the cleat receiver
rail is declared as touching the back shell but measures a deliberate 0.100 mm
registration clearance.

### Plate 5 · 03 screen trim ×2 + 06 knob ×2, silver silk PLA — printed clean
Printed from `main` after the trim-rebate fix, and good. This is the first
confirmation that dropping the rebate worked: the trim ring is now a flat
part that sits proud on the face, with nothing printing over air.

**Still unconfirmed on these parts**, so don't read this as a fit pass:

- **The trim ring against 01a.** 01a has not been reprinted since the fix, so
  the ring has not yet been offered up to the plate it screws to.
- **The knob's D-bore against a real encoder.** `KNOB_BORE_FLAT = 4.6 mm` is
  0.1 mm clearance over an **assumed** 4.5 mm shaft flat (`KY_SHAFT_FLAT_W`,
  marked ASSUMED in the CAD — the 6.0 mm round diameter is verified, the flat
  is not). If your encoder's flat is wider than 4.5 mm the knob will not seat;
  if it is narrower the knob goes on but rotates on the flat until the radial
  M3 set screw bites, which is recoverable.

The encoder had not arrived at the time of this print, so **the flat is still
unmeasured**. If you have a KY-040 in hand before we do, measure across the
flat and report the number — it is the last dimension in this build taken from
a listing rather than a datasheet, and one measurement closes it for everyone.

### Plate 4 · 08 speaker cup + 11 wall cleat + 12 receiver rail — printed, looks right
### Plate 6 · 07 gold tab ×3 — printed, looks right
Both printed and correct on inspection. Neither has been **fitted** yet: the
cup, cleat, rail and tab all mate with body parts that are mid-reprint, so the
real checks — does the cleat hang flat with the rail engaged, does the speaker
seat in the pod, does the tab press into its pocket — are still open.

None of these parts has changed since they were printed, so they will not need
reprinting.

## 2026-09-24 · plate 3 reprinted · Bambu Lab A1, 0.20 mm, matte black PLA

### The column closes now — but three of four screws foul, and the seam had no holes

The reprinted plate 3 **seats and closes correctly**, so the perimeter-boss
fix worked. Fitting it then found the screws and screw bosses fouling the
shell's internal structure. Two separate faults came out of that, one of them
far more serious than the thing being reported.

#### Fault 1 · three of four column screws run into the seam ribs

Measured on the exported CAD, sweeping each screw axis through the shell:

| Screw | On-axis obstruction |
|---|---|
| X 72.56, Z 18.00 | **49.50 mm of solid**, Y 12.50→62.00 |
| X 72.56, Z 185.24 | **49.50 mm of solid**, same span |
| X 146.76, Z 18.00 | clears the shank, fouls at head diameter |
| X 146.76, Z 185.24 | clear |

Three foul, one is clean — exactly what the builder reported.

The obstruction is the **seam bosses and their support ribs** (X 65.00–77.00,
Y 12.50–62.00). Those ribs were added in an earlier round to cure a slicer
warning about a boss cantilevered in mid-air, and nothing re-checked them
against the perimeter screws already sharing that space.

**Why nothing caught it:** `01b` against `02b` measures **0.00 mm³ overlap,
0.0000 mm minimum distance**. The two solids genuinely do not touch — the
*fastener that passes between them* does. No check modelled the fastener.

**Fixed** by relieving the screw's real swept envelope out of the seam
material. No screw or seam-bolt position moved.

#### Fault 2 · all four seam bolts had no hole at all

Found while verifying the first fix. The shell contained **zero cylindrical
features running along X** — no seam bore anywhere in the part. Probing each
bolt position:

```
material inside the bore = 81.68 mm³ of 81.68 mm³   — completely filled, all four
```

A bolt would have met **12.25 mm of continuous solid**. As printed, **the
column module could not be bolted to the screen module at all.**

The cause was boolean ordering: the code cut the insert bore, then fused the
support rib over the same region, filling it straight back in. The bore was
cut correctly and then destroyed by a later operation.

**Fixed** by restructuring the build so every fuse happens before every cut,
which makes the ordering safe by construction rather than by getting it right
once. The insert also moved to the boss's near face and a clearance bore now
runs through the shell wall to reach it, so the bolt has a continuous path.
Verified through both shells: bore 0.00 mm³ obstructed at all four positions,
approach clear, with the expected 3 mm of blind material behind each insert.

#### New checks, both proven to fail on the old geometry first

- **fastener-access** — sweeps each fastener's real envelope (thin shank the
  whole travel, widening to the countersink only at the entry) through every
  part it should pass clear of. Covers all 20 fastener positions.
- **bore-stays-open** — asserts on the *finished* part that each insert bore
  is actually open. This is the one that catches a hole cut correctly and then
  refilled by a later operation, which is invisible to every other check.

That makes four fastener checks, and they are not redundant: one proves the
hole exists, one proves there is material around it, one proves you can reach
it, and one proves nothing filled it back in afterwards.

#### Reprint

**`02b` back shell, column (plate 3) only** — volume changed by −995.64 mm³.
`01b` on the same plate is untouched, as is every other part in the build,
verified part by part on volume and bounding box. All nine plates slice with
no warnings.

## 2026-09-25 · first fit coupons printed, and what they found

### Coupons A and C — both PASS

Plate 1 of the coupon project printed all seven black-PLA pieces.

- **A (screen corner) passed.** The boss presses into the wall opening and
  seats flush by hand. Worth noting A deliberately tests the *worst* case: the
  one boss narrow enough to need a reduced diameter because the standard 9 mm
  would not fit there. **Validates the 2026-09-22 boss/wall fix.**
- **C (band mount) passed.** The stack clamps flat. **Validates the
  2026-09-23 fix**, where the mounting holes had removed 0.00 mm³ and the
  hardware floated with nothing to clamp against.
- **B could not be tested** — no screw long enough. The holes line up
  visually, which does confirm the seam bores exist and are coaxial.

That last point turned out to matter far more than it sounded.

### The screws were never checked for length — none of them

There is no screw long enough because **no real screw would work**. Measured
on the exported CAD:

| Joint | Specified | Reality |
|---|---|---|
| Face plate → shell (screen) | M3 × 12 | needs ~49 mm — **32 mm short** |
| Face plate → shell (column) | M3 × 12 | needs ~61 mm — **44 mm short** |
| Seam bolts | M3 × 16 | max usable **12.21 mm** — bottoms out, head **3.79 mm proud** |
| Trim ring | M3 × 8 | pilot only **2.90 mm** — bottoms out |

**18 of 25 fasteners were specified wrong.** The face plate's boss ended
10.1 mm in, the shell's back wall sat 45–56 mm further back, and between them
was *nothing* — the screw was expected to cross open air.

**Why nothing caught it:** every check modelled the **hole**. None modelled
the **screw** as an object with a length. Feature-exists, access, bore-open,
minimum-wall — all correct, all passing, all blind to the one property that
made the joint impossible.

**Fixed:** the face-plate bosses now run the real depth of the shell
(48.56 mm screen, 60.56 mm column, both derived from the shell depth rather
than restated), with the insert recessed 3.6 mm from the clamping tip so an
M3 × 12 gets 5.30 mm of engagement instead of bottoming out. Each boss carries
a printed gusset, because a bare Ø9 column 50–60 mm tall is the floating
cantilever this project has already fixed four times, and slicer supports
cannot be cleared out of a blind bore.

Seam bolts become **M3 × 12** and trim screws **M3 × 3** — documentation and
BOM changes only, no geometry.

**New check — fastener length.** Models every fastener as a real object and
asserts the specified screw reaches and engages. It fails on the old geometry
reporting all four faults above.

**Also fixed: the check runner could never fail.** `freecadcmd` exits 0 even
when an assertion fires — it prints the error and returns success. Every
"exit 0, all checks passed" in this project's history was reading a number
that could not report failure. All 72 assertions now exit non-zero properly,
verified by forcing a failure.

### One more, found while fixing the above

The speaker back-cup's countersink was cut on the face that mates against the
shell, instead of the outward face. Its **volume and bounding box are
completely unchanged** — only the countersink moved, 77.18 mm³ of material.
A reprint list derived from volume and bounding box would have missed it
entirely. It needs reprinting.

### Reprint after this fix

**01a, 01b, 02b and 08.** Plates 1 and 3 get longer: plate 1 goes from
1 h 31 m to **2 h 06 m**, plate 3 from 4 h 34 m to **4 h 57 m**. All nine
plates slice with no warnings.

### Still open

The seam bolt's head bears on the screen shell's *cavity-side* wall, so it
must be driven **before** that module is closed — but the assembly order
closes the screen module at step 9 and drives the seam bolts at step 11. That
ordering needs resolving before anyone follows the instructions literally.

### Plates 1 and 2 reprinted — the screen module fits together

First time the two halves of the screen module have gone together. `01a` seats
into `02a` cleanly, and the screw holes and bosses line up. The silver trim
ring — printed back on 2026-09-23, on a different plate in a different round —
drops onto the face plate correctly.

Three separate fixes are confirmed at once, at full scale rather than on a
coupon:

- **The perimeter boss/wall overlap** (2026-09-22) — the plates now nest.
- **The long perimeter bosses** (2026-09-25) — brand-new geometry, six Ø9
  columns ~49 mm tall with gussets, and they land on the back wall's holes.
- **The trim rebate removal** (2026-09-22, the very first real-print defect) —
  the ring seats on a flat face, and a part from an earlier round still mates
  with a part reprinted two rounds later.

**What this does not yet prove.** The parts were offered up, not screwed
together. The fastener-length fix — M3 × 12 reaching 5.30 mm of engagement
through a 6.70 mm travel — is still unconfirmed in the real world, and it is
the fix this whole round existed for. Holes lining up by eye is good evidence
of alignment and nothing at all about reach.

**The test worth doing next:** drop an M3 × 12 through a back-wall hole. It
should enter the boss's bore with the head sitting down in its countersink. To
actually thread it, that boss needs its heat-set insert first.

Minor print-quality points on plate 2 are still to be reviewed.

## Where the build stands

**All nine plates have now been printed at least once.** What is current and
what is stale:

| Plate | Parts | State |
|---|---|---|
| 1 | 01a face plate, screen | **current** — reprinted 2026-09-25, fits 02a |
| 2 | 02a back shell, screen | **current** — reprinted 2026-09-25, fits 01a |
| 3 | 01b + 02b column | **reprint both** — 01b long bosses, 02b screw access + seam bores |
| 4 | 08 cup, 11 cleat, 12 rail | **reprint 08** — countersink was on the mating face (11 and 12 are current) |
| 5 | 03 trim ×2, 06 knob ×2 | current — coupon C passed |
| 6 | 07 gold tab ×3 | current, fitting pending |
| 7 | 05 band diffuser | **reprint** — new mounting geometry |
| 8 | 04a IGNITION insert | **reprint** — new mounting geometry |
| 9 | 04b NIGHTFALL insert | **reprint** — new mounting geometry |

Six plates to re-run, three good. **A full fitting is deliberately deferred
until the body parts are reprinted** — most of the remaining unknowns are
fits between a body part and something that bolts to it, and there is no
point testing those against superseded geometry.

Still worth checking as they come off:

- **Plate 1:** is the window edge clean, and does the raised trim ring look right?
- **Plate 2:** does the USB-C plug pass through the cable slot? Does the 10 mm LED strip seat fully in the band groove?
- **Plate 3:** the engraved dial ticks, and whether the KY-040 bushing and the KCD1 rocker fit their openings (both unconfirmed dimensions from listings).
- **Plate 4:** does the cleat hang flat, with the rail engaged?
- **Plate 7:** does the speaker sit in the pod, and does the diffuser clear the cone?
- **Plates 7–9 together:** do the insert and diffuser now actually bolt to the
  four bosses, flush, with the screws reaching? That is the whole point of the
  last fix and it is the one thing no check can settle.

## 2026-09-25 · stringing at the speaker opening and the light vents

Plates 1 and 2 reprinted cleanly and fit, with one print-quality complaint:
**stringing across the speaker opening and inside the light vents** on `02a`.
Cosmetic — it cleans up with a pick — but worth understanding rather than
tolerating.

**Cause, found in the project's own slicer settings rather than guessed:**

```
reduce_crossing_wall = 0      ("Avoid crossing walls", off)
retraction_length    = 0.8 mm @ 30 mm/s
nozzle_temperature   = 220 °C (PLA)
```

With *avoid crossing walls* off, a travel move takes the straight line to
wherever it is going — **including straight across an opening**. Every layer
containing a hole means the nozzle drags a molten strand over the void. That is
exactly why the stringing clusters at the speaker opening and the vents and the
solid areas of the same part are clean: solid areas have short travels over
material, openings force long travels over air. The speaker opening is the
worst of them because the pod tube stands right in it, so every layer of the
tube hops between the tube wall and the outer shell.

**Fixed in the shipped project:** `reduce_crossing_wall` is now on, so travels
route around holes instead of over them. Cost is a few minutes per plate — the
long plates go up about 2–9 minutes, roughly 2%.

**If it persists, tune in this order** — the settings, not the model:

1. **Nozzle temperature.** 220 °C is the warm end for PLA. Try 210; ooze falls
   off quickly with temperature. This is the biggest remaining dial.
2. **Dry the filament.** PLA that has been open for weeks strings regardless of
   settings, and no travel setting fixes wet filament.
3. **Retraction.** 0.8 mm at 30 mm/s is the A1 default. Going to 1.0 mm helps a
   little, but it is a smaller effect than temperature.

Nothing here is a model defect, and no part changes.

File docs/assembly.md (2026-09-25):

# Assembly

About two hours, once everything is printed. No glue anywhere: heat-set
inserts and M3 screws, plus one soldered splice for the mic cut.

Every screw goes in from the back or from inside, so the finished front has
no visible fastener.

> The drawings are generated from the CAD, so they match the parts exactly.
> Each one states its viewpoint, e.g. *front-right 3/4*. Regenerate them with
> `python3 docs/assembly/build_steps.py`.

## Before you start

**Printed** (see [print settings](../README.md#printing-on-a-bambu-lab-printer)): all of `stl/common/`, plus one band insert —
`stl/ignition/` **or** `stl/nightfall/`.

**Bought:** everything in [`bom/bom.csv`](../bom/bom.csv).

**Tools:** soldering iron with a heat-set insert tip (or a flat tip), 2.5 mm
hex key, small Phillips screwdriver, wire strippers, side cutters.

**Fasteners used**

| Where | Size | Count |
|---|---|---|
| Face plate → back shell (screen) | M3 × 12 | 6 |
| Face plate → back shell (column) | M3 × 12 | 4 |
| Seam, screen module → column | M3 × 12 | 4 |
| Display → back shell | M2.5 (supplied with the display) | 4 |
| Speaker back-cup | M3 × 8 | 4 |
| Trim ring | M3 × 3 (self-tapping) | 4 |
| Band insert + diffuser | M3 × 8 | 4 |
| Cleat receiver rail | M3 × 8 | 3 |
| Wall cleat → wall | #8 wood screws + anchors | 2 |

---

## 1 · Heat-set the inserts

Step 1

Melt an M3 insert into every boss marked here: the back of both face plates
(01a, 01b), the perimeter and seam bosses of both back shells (02a, 02b), and
the receiver rail (12). The trim ring (03) is the one exception — its own
mounting boss is too shallow for a heat-set insert once it clears the
display's own housing, so it takes a self-tapping M3 × 3 directly into
the boss, no insert (see step 8).

Set the iron to about 240 °C, press each insert in square, and stop when its
top is flush. Let them cool before you screw into them. **Take your time
here:** a crooked insert is the most common way one of these builds goes
wrong.

## 2 · Fit the receiver rail to the back shell

Step 2

The rail (12) is what the panel later hangs on. It goes on **now**, because
its screws are driven from inside the cavity, which closes in step 9.

Sit the rail in the shallow recess on 02a's back wall — the recess locates it,
so there's nothing to measure — and drive 3 × M3 × 8 from inside the cavity.

## 3 · Mount the display and the Pi

Step 3

With the Pi 5 and its Active Cooler already bolted to the back of the Touch
Display 2, lower the whole module into 02a through the open front.

Drive 4 × M2.5 (the display's own screws) from **outside** the back wall into
the display's mounting holes. Route the display's power leads and the FPC
cable clear of the speaker pod.

## 4 · Speaker, amp, level shifter

Step 4

Press the 40 mm speaker into the pod shoulder from the **front**, through the
band opening — it won't fit once the band insert is on. Screw the back-cup
(08) on from outside the back wall, 4 × M3 × 8. That seals the speaker's
chamber, so seat it evenly.

Drop the MAX98357A amp and, if you're using it, the 74AHCT125 level shifter
into their trays. They're friction fits; don't force them.

## 5 · LED strips

Step 5

Two runs, both on 02a:
- **Band:** about 12 LEDs in the groove behind the band window, facing forward.
- **Wall wash:** about 40 LEDs in the channel around the rear perimeter, facing the wall.

Cut only on the marked copper pads. Feed both sets of leads toward the Pi.

## 6 · Microphone and the mic cut

Step 6

Sit the USB mic dongle in the cradle inside 02b, facing the row of ports along
the top edge.

Then wire the mic cut, which is the one bit of soldering:
cut **only the red wire** of the USB extension, solder both ends to the
rocker's two terminals, and insulate each joint with heat-shrink. Off then
physically removes the microphone's power. Full detail in
[wiring.md](wiring.md).

## 7 · Wire it up

No drawing for this one — follow [wiring.md](wiring.md) pin by pin, then
append [config.txt](config.txt) to `/boot/firmware/config.txt` on the Pi's
card.

**Power up and test before you close anything:** the screen should light, the
dial should move the focus, pressing it should select, and the speaker should
play. It is much easier to fix now than after the panels are on.

## 8 · Dress the face plate

Step 8

On 01a:
- **Trim ring (03):** sits on the front face, standing about 1.5 mm proud, and screws from behind, 4 × M3 × 3 self-tapping (this mount is a shallow self-tap into the boss itself, not a heat-set insert — see step 1 — so it needs the shortest screw in your kit, not the general M3 × 6-16 mm assortment; source separately if needed).
- **Band insert** (your team's) and **diffuser (05)**: stack them behind the band window and screw both into the same bosses, 4 × M3 × 8. The diffuser's hole goes over the speaker.

## 9 · Close the screen module

Step 9

Lower 01a onto 02a, watching that no wires are pinched at the rim. Drive
6 × M3 × 12 from the **back**, through the shell into the face plate's bosses.

## 10 · Build the control column

Step 10

On 01b, from the front:
- **Dial (KY-040):** through the bushing hole, held by its own M7 nut.
- **Rocker:** snaps into its cutout.
- **Gold tab (07):** press-fits into its pocket under the rocker.

Then close 01b onto 02b with 4 × M3 × 12 from the back.

## 11 · Join the two modules

Step 11

Stand the screen module and the column face to face, so their side walls
meet, and drive 4 × M3 × 12 through 02a into the column's bosses. Keep the
front faces flush as you tighten.

## 12 · Knob

Step 12

Push the knob onto the encoder's D-shaft, with the pointer at the flat.
It should need a firm push. If it's loose, a drop of the M3 set screw in its
radial pilot hole holds it.

## 13 · Hang it

Step 13

Screw the wall cleat (11) to the wall — into a stud if you can, otherwise
drywall anchors — with its 45° face pointing **up and toward the wall**.
Check it's level.

Hook the panel's rail over it and let go. The weight wedges the two 45° faces
together, and the panel sits 66.6 mm off the wall. Route the USB-C power
cable out of the slot in the bottom edge.

---

## If something doesn't fit

The rocker cutout, the dial's shaft flat and the speaker's depth all came from
listing photos rather than datasheets, so they are the likeliest to need a
tweak. Each is a single named value in `cad/generate_parts.py`; change it and
regenerate. Please also report it in
[print-log.md](print-log.md) so the next builder doesn't hit it.

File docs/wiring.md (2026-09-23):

# Wiring

Everything plugs into the Raspberry Pi 5. There are **15 jumper wires, one
soldered splice, and (optionally) one small chip on a scrap of perfboard**.

If you have never wired a Pi before, this page is written for you: do the
sections in order, and test after each one.

Overview

---

## Before you touch a wire

1. **Unplug the Pi.** Never move a jumper with power on.
2. **Know where pin 1 is.** It's the corner nearest the USB-C power socket.
   Hold the board with the header on the right and pin 1 at the top, exactly
   as in the map below. **Counting from the wrong end is the most common
   mistake, and on pin 1 it means 5 V into a GPIO.**
3. **Pins are counted in pairs:** odd numbers down the left column, even
   numbers down the right. 1 and 2 are side by side.

Pi 5 header map

### Wire colours

Not required, but the diagrams use them and it makes a photo readable:

| Colour | Means |
|---|---|
| Red | 5 V |
| Orange | 3.3 V |
| Black / grey | ground |
| Cyan, violet, green, yellow | signals |

---

## 1 · The dial

Dial wiring

Five female-to-female jumpers, no soldering.

| KY-040 pad | Pi pin | Pi name | Colour |
|---|---|---|---|
| `+` | **1** | 3V3 | orange |
| `GND` | **9** | GND | black |
| `CLK` | **11** | GPIO17 | cyan |
| `DT` | **13** | GPIO27 | cyan |
| `SW` | **15** | GPIO22 | yellow |

> **`+` goes to pin 1 (3.3 V), never to 5 V.** The module's pull-up resistors
> would then put 5 V onto a GPIO, which can damage the Pi. GPIOs are 3.3 V only.

**Test** (after adding `config.txt`, below): `sudo apt install evtest`, run
`evtest`, choose the `rotary` device, and turn the dial. You should see
`REL_X` events, one per click. Choose the `dial-push` device and press: you
should see `KEY_ENTER`.

---

## 2 · The amp and speaker

Audio wiring

| Amp pad | Pi pin | Pi name | Colour |
|---|---|---|---|
| `Vin` | **4** | 5V | red |
| `GND` | **39** | GND | black |
| `BCLK` | **12** | GPIO18 | violet |
| `LRC` | **35** | GPIO19 | violet |
| `DIN` | **40** | GPIO21 | violet |

The speaker's two tags go to the amp's `+` and `−` screw terminals. With one
speaker, polarity doesn't matter.

> **Leave `SD` and `GAIN` unconnected.** On the Adafruit board (and most
> clones) `SD` is held high by a 1 MΩ resistor to Vin, so the amp is already
> enabled — wiring `SD` to a GPIO is a common way to end up with silence.
> `GAIN` unconnected gives 9 dB, which suits this speaker.
> ([Adafruit pinout](https://learn.adafruit.com/adafruit-max98357-i2s-class-d-mono-amp/pinouts))

Most of these boards ship with loose headers: solder them, or buy one
pre-soldered.

**Test:** `speaker-test -c1 -t sine -f 440 -l1`. You should hear a tone.
`aplay -l` should list a `MAX98357A` card.

---

## 3 · The LEDs

LED wiring

| From | To | Colour |
|---|---|---|
| Pi pin **4** (5V) | both strips' `5V`, amp `Vin`, shifter pin 14 | red |
| Pi pin **34** (GND) | both strips' `GND`, shifter pin 7 | black |
| Pi pin **19** (GPIO10) | shifter pin 2 (`1A`) | green |
| Shifter pin 3 (`1Y`) | 330 Ω resistor → band strip `DIN` | green |
| Band strip `DOUT` | wall-wash strip `DIN` | green |
| Shifter pin 1 (`OE1`) | ground | black |

**Strips have a direction.** The arrows printed on them point away from the
`DIN` end. Wire into `DIN`; cut only on the marked copper pads.

> **Power.** 52 LEDs at full white would draw about 3 A, far more than the
> Pi's 5 V pins should supply. `config.txt` caps brightness at 64 of 255, which
> keeps the worst case near 0.8 A. Keep that cap. Solder the 5 V split rather
> than stacking Dupont ends, and use 22 AWG for this run.

**The level shifter is optional.** WS2812Bs want a data high near 5 V, and the
Pi gives 3.3 V. Many strips work anyway. Try without it (GPIO10 straight to
the resistor); if the LEDs flicker or show wrong colours, add it.

---

## 4 · The mic cut

Mic cut wiring

This is the one soldered joint, and the reason the panel can claim a real
privacy switch: the rocker breaks the microphone's **power**, so when it's off
the Pi cannot see the mic at all.

1. Open the USB extension's jacket about 10 cm from the female end.
2. **Cut only the red wire.** Leave white, green, black and the shield alone.
3. Strip about 5 mm from each cut end.
4. Slide heat-shrink onto the wires **before** soldering.
5. Solder one end to each rocker terminal, then shrink the tubing.

Plug the male end into a Pi USB port and the mic into the female end.

**Test:** `arecord -l` with the rocker on lists a USB audio device; with it off,
the device disappears. Record five seconds: `arecord -d 5 -f cd mic.wav`, then
`aplay mic.wav`.

---

## 5 · Display and power

- **Display ribbon:** the standard-to-mini FPC cable from the display's box,
  into either MIPI connector on the Pi.
- **Display power:** the supplied lead to pins **2** (5 V, red) and **6**
  (GND, black).
- **Pi power:** the 27 W USB-C supply, into the Pi, out through the slot in
  the bottom edge. Use the straight plug, not a right-angle adapter: an
  adapter can drop the Pi out of its 5 A power mode.

---

## 6 · Configuration

Append [`config.txt`](config.txt) to `/boot/firmware/config.txt`, then reboot.
It loads four stock drivers: the amp, the dial's rotation, the dial's push,
and the LEDs. No custom drivers, nothing to compile.

One line may need changing: if your encoder has 30 detents instead of 20,
change `steps-per-period=1` to `2`.

---

## If something doesn't work

| Symptom | Most likely cause |
|---|---|
| Nothing at all, Pi won't boot | Power. Use the 27 W supply and the straight plug. |
| Screen dark, Pi running | Ribbon in the wrong way round, or display power not on pins 2 and 6. |
| No sound, `aplay -l` shows no card | `dtoverlay=max98357a,no-sdmode` missing, or BCLK/LRC/DIN on the wrong pins. |
| No sound, card is listed | Speaker wires loose, or volume muted (`alsamixer`). |
| Dial turns the wrong way | Swap `CLK` and `DT`, or swap the pins in `config.txt`. |
| Dial skips or double-steps | Wrong `steps-per-period` for your encoder. |
| Dial does nothing | `+` on the wrong pin, or GND missing. |
| Push does nothing, turning works | `SW` not on pin 15. |
| Mic never appears | The red wire isn't joined through the rocker, or a data wire was cut. |
| LEDs dead | Wired into `DOUT` instead of `DIN`, or no shared ground. |
| LEDs flicker or wrong colours | Add the level shifter; check the 330 Ω resistor. |
| First few LEDs work, rest don't | Brightness too high for the 5 V rail, or a bad joint mid-strip. |

Found something this table doesn't cover? Please add it, or open an issue —
see [print-log.md](print-log.md).

---

## Where these numbers come from

- Pi 40-pin header: the standard Raspberry Pi pinout (Pi 5 keeps it).
- `max98357a`, `rotary-encoder`, `gpio-key`, `ws2812-pio`: the overlay README
  in `raspberrypi/firmware`.
- Amp `SD`/`GAIN` behaviour: Adafruit's MAX98357A pinout page (linked above).
- Everything else: `bom/bom.csv`, which lists the exact part each pin assumes.

The diagrams are generated by `docs/wiring/build_diagrams.py`.

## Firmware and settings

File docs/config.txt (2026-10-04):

# Dial Panel -- append to /boot/firmware/config.txt (Raspberry Pi OS Trixie)
# Overlay names/parameters checked against raspberrypi/firmware boot/overlays/README, 2026-09-21.

# Audio: MAX98357A on GPIO18 (BCLK) / GPIO19 (LRCLK) / GPIO21 (DIN); SD_MODE not driven, keeps GPIO4 free
dtoverlay=max98357a,no-sdmode

# Dial turn: rotary encoder on GPIO17 (A) / GPIO27 (B) as a RELATIVE axis (like a scroll wheel).
# steps-per-period=1 suits 20-detent/20-pulse KY-040s; use 2 if yours is 30 detent / 15 pulse.
dtoverlay=rotary-encoder,pin_a=17,pin_b=27,relative_axis=1,steps-per-period=1

# Dial push: GPIO22, active low, internal pull-up -> KEY_ENTER (28)
dtoverlay=gpio-key,gpio=22,active_low=1,gpio_pull=up,keycode=28,label="dial-push"

# LEDs: RP1 PIO driver on GPIO10, 52 pixels, brightness capped ~25% for the Pi's 5 V budget -> /dev/leds0
dtoverlay=ws2812-pio,gpio=10,num_leds=52,brightness=64
# (Fallback instead of ws2812-pio: dtparam=spi=on and drive MOSI/GPIO10 with pi5neo or Adafruit neopixel_spi)

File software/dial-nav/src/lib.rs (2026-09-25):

//! Dial Panel navigation — the interaction model, as pure logic.
//!
//! Turn to move focus. Push to open. Turn to adjust inside a tile. There is no
//! back button: you leave a tile by pushing, or by letting it time out and go
//! home on its own.
//!
//! This crate deliberately knows nothing about the device. It reads no GPIO, no
//! files and no clock — time arrives as [`Event::Tick`], input arrives as
//! [`Event::Turn`] and [`Event::Push`], and the result is a [`Frame`] a host
//! draws however it likes. That is what lets the same logic run under the
//! desktop harness and on the panel unchanged, and it is why the eight-second
//! idle reset can be unit-tested without waiting eight seconds.
//!
//! What this crate does *not* decide: colour. Focus is reported as an index and
//! a mode; the xxx5 rule that focus is a white ring and never a colour is the
//! renderer's to keep.

use std::time::Duration;

/// How long a tile stays open with no input before the panel goes home.
///
/// The concept sheet says "about 8 seconds". Whether this is adjustable, and by
/// whom, is an open question for `ux-engineer` and DJ — so it is a parameter
/// here rather than a constant, and nothing in this crate assumes the default.
pub const DEFAULT_IDLE_TIMEOUT: Duration = Duration::from_secs(8);

/// Tuning that a host may legitimately vary.
#[derive(Debug, Clone, Copy, PartialEq, Eq)]
pub struct Config {
    /// Idle time before an open tile returns home.
    pub idle_timeout: Duration,
    /// Whether focus wraps past the ends of the tile row.
    ///
    /// A continuous rotary control has no end-stop to feel, so wrapping is the
    /// honest default: the dial never "hits a wall" that the hand cannot sense.
    pub wrap_focus: bool,
    /// Whether the idle reset also returns focus to the first tile.
    ///
    /// Default `false`: going home is about leaving a tile, not about forgetting
    /// where you were standing. **Open question** for `ux-engineer` — a wall
    /// panel that always greets you at the same tile is a defensible other
    /// answer, so this is a switch rather than a decision baked into the code.
    pub idle_resets_focus: bool,
}

impl Default for Config {
    fn default() -> Self {
        Self {
            idle_timeout: DEFAULT_IDLE_TIMEOUT,
            wrap_focus: true,
            idle_resets_focus: false,
        }
    }
}

/// What a tile does when you push it.
#[derive(Debug, Clone, PartialEq, Eq)]
pub enum TileKind {
    /// Opens, and turning adjusts the value live — a dimmer, a volume, a setpoint.
    Range {
        min: i32,
        max: i32,
        /// Value change per detent of the dial.
        step: i32,
        /// Suffix a renderer may show after the number, e.g. "%" or "°".
        unit: String,
    },
    /// Flips on push. Does not open a screen — there is nothing to adjust.
    Toggle,
    /// Fires once on push. Does not open a screen.
    Action,
    /// Opens to be read. Turning does nothing; it goes home on push or on idle.
    Info,
}

/// One thing on the home screen.
#[derive(Debug, Clone, PartialEq, Eq)]
pub struct Tile {
    /// Stable identifier for the host to map onto whatever it controls.
    pub id: String,
    /// Human label. Copy is `ux-engineer`'s; this crate only carries it.
    pub label: String,
    pub kind: TileKind,
}

impl Tile {
    pub fn range(id: &str, label: &str, min: i32, max: i32, step: i32, unit: &str) -> Self {
        Self {
            id: id.to_string(),
            label: label.to_string(),
            kind: TileKind::Range {
                min,
                max,
                step,
                unit: unit.to_string(),
            },
        }
    }

    pub fn toggle(id: &str, label: &str) -> Self {
        Self {
            id: id.to_string(),
            label: label.to_string(),
            kind: TileKind::Toggle,
        }
    }

    pub fn action(id: &str, label: &str) -> Self {
        Self {
            id: id.to_string(),
            label: label.to_string(),
            kind: TileKind::Action,
        }
    }

    pub fn info(id: &str, label: &str) -> Self {
        Self {
            id: id.to_string(),
            label: label.to_string(),
            kind: TileKind::Info,
        }
    }
}

/// A tile's current state.
#[derive(Debug, Clone, Copy, PartialEq, Eq)]
pub enum Value {
    Number(i32),
    OnOff(bool),
    /// Actions and info tiles hold nothing.
    None,
}

impl Value {
    pub fn as_number(self) -> Option<i32> {
        match self {
            Value::Number(n) => Some(n),
            _ => None,
        }
    }

    pub fn as_on_off(self) -> Option<bool> {
        match self {
            Value::OnOff(b) => Some(b),
            _ => None,
        }
    }
}

/// Input, as the device produces it.
///
/// The rotary encoder is configured as a *relative* axis, so a turn arrives as a
/// signed count of detents rather than an absolute position. A fast spin can
/// deliver several at once, which is why [`Event::Turn`] carries a delta instead
/// of being a single-step "next"/"previous".
#[derive(Debug, Clone, Copy, PartialEq, Eq)]
pub enum Event {
    /// Detents turned; positive is clockwise.
    Turn(i32),
    /// The dial was pushed. On the device this arrives as `KEY_ENTER`.
    Push,
    /// Time passed. The host decides how often; accuracy of the countdown is
    /// bounded by how fine these are.
    Tick(Duration),
}

/// Which screen is showing.
#[derive(Debug, Clone, Copy, PartialEq, Eq)]
pub enum Screen {
    Home,
    /// A tile is open. Only `Range` and `Info` tiles can be open — `Toggle` and
    /// `Action` do their work and stay home.
    Tile {
        index: usize,
    },
}

/// Why the panel went home.
#[derive(Debug, Clone, Copy, PartialEq, Eq)]
pub enum HomeReason {
    /// The dial was pushed.
    Push,
    /// Nobody touched it for [`Config::idle_timeout`].
    Idle,
}

/// Something happened that the host may want to act on — light an LED, play a
/// tone, switch a relay.
///
/// Returned rather than performed, because this crate does not touch hardware.
#[derive(Debug, Clone, PartialEq, Eq)]
pub enum Effect {
    FocusMoved {
        index: usize,
    },
    Opened {
        index: usize,
    },
    ValueChanged {
        index: usize,
        value: i32,
    },
    /// A range tile was turned but the value did not move, because it is already
    /// at its limit. Worth surfacing: it is the moment a device should feel like
    /// it hit an end-stop rather than feeling broken.
    ValueAtLimit {
        index: usize,
        value: i32,
    },
    Toggled {
        index: usize,
        on: bool,
    },
    ActionFired {
        index: usize,
    },
    WentHome {
        reason: HomeReason,
    },
}
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

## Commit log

2026-09-22 Initial release staging: Dial Panel (hw-2015)
    A wall-mounted smart-home panel, fully 3D-printable, driven by one
    push-dial. Both color schemes (A Ignition, B Nightfall) ship in one
    release as swappable band inserts.
    - cad/: parametric FreeCAD source + STEP exports; regenerates every part
    and runs the full check suite (31/31 feature probes, 27/27
    interference pairs, sound path, wall-cleat engagement)
    - stl/: common parts + one band insert per team; watertight, manifold
    - bom/bom.csv: one Amazon cart, every listing checked 2026-09-21
    - docs/: wiring, config.txt (stock Pi 5 overlays), team guide, drawings
    - Code Apache-2.0, design files CC-BY-4.0
    Pre-release: CAD-verified, not yet printed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
    [01a-face-plate-screen.step, 01a-face-plate-screen.stl, 01b-face-plate-column.step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]
2026-09-22 Fix bom.csv quoting so GitHub renders it (#1)
    The silver-silk filament row had quotes inside an unquoted field
    (line 21), which is invalid CSV. Rewrote the file through a CSV writer
    so every field is quoted correctly. Values unchanged.
    [bom.csv]
2026-09-22 Add a generated Amazon shopping list to the README (#2)
    * Add a one-click Amazon cart link for the full BOM
    bom/cart_link.py builds Amazon's multi-item add-to-cart URL from bom.csv
    (new cart_qty column: packs to buy; 0 for parts in the Pi kit or with no
    listing) and writes it into the README between CART-LINK markers. It fails
    loudly if a row to buy has no plain amazon.com/dp/<ASIN> URL, and asserts
    the link carries no affiliate tag.
    * Replace the cart button with a generated shopping list
    Amazon's multi-item add-to-cart URL no longer adds items (tested
    signed in: it opens an empty cart). bom/shopping_list.py now writes a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
    [bom.csv]
2026-09-22 Add a Bambu Studio project; print-oriented STLs; fix print defects (#3)
    Bambu:
    - bambu/dial-panel-hw-2015.3mf: 9 named plates, every part pre-oriented and
    on its filament (matte black, silver silk, yellow, clear PETG), A1 0.4 mm on
    the Textured PEI plate. Print plates 1-7 plus 8 (Ignition) or 9 (Nightfall).
    - bambu/build_project.py rebuilds it through Bambu Studio's CLI (flattening
    the A1 profiles, which the CLI won't resolve), writes the same meshes to
    stl/, and slices every plate as a check: any warning fails the build.
    Every plate slices, support off, no warnings.
    CAD (found by slicing every plate):
    - 01b: detent ticks engraved instead of raised (face-down it stood on them)
    - 0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
    [01a-face-plate-screen.step, 01a-face-plate-screen.stl, 01b-face-plate-column.step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]
2026-09-22 Fix the printed defect: drop 01a's trim rebate; catch the class (#4)
    DJ's first real print of 01a (face plate) failed around the screen window:
    the trim rebate is a pocket in the BED face, so its ledge printed over air
    and left stringing and deformed edges. Bambu's slicer did not warn.
    - 01a: the front trim rebate is removed; the front is one flat plane apart
    from real through-openings. First-layer contact is now 100%.
    - 03-screen-trim: sits on the flat front face, proud by 1.5 mm, still
    fastened from behind through a widened bore, so no visible fastener.
    - New check across all 13 parts: any downward-facing surface with only air
    beneath it. A cantilever spanning more than 10 mm now FA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
    [01a-face-plate-screen.step, 01a-face-plate-screen.stl, 01b-face-plate-column.step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]
2026-09-23 Add assembly docs with generated step drawings, and a print log (#5)
    * Add a print log; record the first two real prints
    Plate 1 (face plate) failed at the trim rebate; plate 2 (back shell) was
    printed pre-fix and strung at the cable-slot ledge, exactly where the new
    bed-face check reported a 16mm unsupported span. Both are fixed on main.
    The log also lists what to check on each remaining plate.
    * Add step-by-step assembly docs with generated drawings
    docs/assembly.md is 13 steps, ordered so nothing traps a later one (the
    receiver rail goes on before the face plate closes the cavity), with the
    fastener size and count per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
2026-09-23 Add wiring diagrams and a beginner-level wiring guide (#6)
    docs/wiring/ has six generated diagrams: an overview, a full Pi 5 header
    map with every used pin called out, and one per subsystem (dial, amp and
    speaker, LEDs, mic cut). docs/wiring/build_diagrams.py generates them.
    docs/wiring.md is rewritten for someone who has never wired a Pi: where
    pin 1 is and how pins are numbered, wire colours, a table per subsystem,
    a test command after each one, and a troubleshooting table.
    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
2026-09-23 Fix face plates fouling their shells; check all pairs (#7)
    DJ printed plates 1-3 and neither face plate would seat: "the screw base
    bumps the edge of the body". The parts genuinely overlapped — 448 mm3 on
    the screen module, 527 mm3 on the column — where the perimeter screw
    bosses ran into the shells side walls.
    The interference list was hand-written and never paired a face plate with
    its own shell, so 27/27 passed while the two biggest parts intersected.
    - geometry fixed; every nesting fit now clears by FIT_CLEARANCE = 0.4 mm
    - interference is now generated from ALL pairs of placed parts (276, one
    named skip: the interchangeable band inserts)
    - new fit-clearance check separates inten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
    [01a-face-plate-screen.step, 01a-face-plate-screen.stl, 01b-face-plate-column.step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]
2026-09-24 Fix the band insert and diffuser having no mounting features (#8)
    * Fix band-mount bosses landing outside 04a/04b/05; add checks that catch it
    The BAND_MOUNTS boss centres sat 1.0mm outside the band insert/diffuser
    outline (WIN_BORDER was raised to fix an earlier defect but
    INSERT_OVERLAP was never re-derived against it), so the Ø3.4 clearance
    holes never actually existed -- cutting one there just nicked a corner
    scallop, removing ~0mm3 instead of a real hole. Even with real holes,
    nothing clamped the stack: INSERT_Y0 carried a stray FIT_CLEARANCE gap
    (a nesting-fit constant misapplied to a clamped joint) and DIFFUSER_Y0
    added its own independent "+1.0" floating offset, so the insert sat
    0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
    [01a-face-plate-screen.step, 01b-face-plate-column.step, 02a-back-shell-screen.step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]
2026-09-24 Log plate 5 as printed clean; keep the D-bore fit open (#9)
    First confirmation that the trim-rebate fix prints cleanly. Records what
    plate 5 does NOT yet confirm: the ring against a reprinted 01a, and the
    knob bore against a real encoder shaft flat, which is still the last
    ASSUMED dimension in the build.
2026-09-24 Tag every commit on main with a rolling version (#10)
    A tag is a specific printable state of the hardware, which matters more here
    than in a software repo: a part printed from an older tag may not fit one
    printed from a newer one.
    Patch counts up automatically; minor and major are deliberate (push v0.2.0
    by hand and the automation picks up from there). No third-party actions.
2026-09-24 Correct the log: all nine plates printed; plates 4 and 6 good (#11)
    Adds plate 4 and 6 entries, records that printing plate 3 is what surfaced
    the boss misalignment that condemned plates 1-3 together, notes the KY-040
    has not arrived so the shaft flat is still unmeasured, and replaces the
    'still to print' list with a per-plate state table: six to re-run, three
    current. Full fitting is deferred until the body parts are reprinted.
2026-09-24 Fix column screws fouling the seam ribs, and seam bores that were filled in (#12)
    * Fix PERIM_B screws fouling the seam boss/rib; add FASTENER-ACCESS check
    A real reprint of plate 3 (01b+02b) closed correctly but the builder
    reported screws fouling internal structure -- confirmed on the exported
    STEP: three of the four control-column perimeter screws ran into the
    seam boss/rib block on 02b's own left wall (up to 670mm3 at the head/
    counterbore diameter), because that seam feature was added in a later
    round than PERIM_B's own Z positions and nothing re-checked one against
    the other. 01b vs 02b's own all-pairs interference read exactly
    0.00mm3 the whole time -- the two finished solids never t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
    [01a-face-plate-screen.step, 01b-face-plate-column.step, 02a-back-shell-screen.step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]
2026-09-25 Dial navigation as a portable module, with a desktop harness (#15)
    The panel's interaction model, written so it can be iterated on without a
    Pi and moved to a Kit later without a rewrite.
    dial-nav has no device in it: Turn/Push events in, Tick(Duration) for
    time, a Frame plus Effects out. No I/O, no clock, no dependencies. The
    same state machine runs under the harness and on the panel unchanged,
    and the eight-second idle reset is tested in microseconds.
    Turn to move focus, push to open, turn to adjust inside a tile, no back
    button, home after ~8s idle with a draining line and "HOME IN n". Tiles
    are Range, Toggle, Action or Info. Adjustment is live rather than a
    dialog you confirm, so leavi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
    [lib.rs, main.rs]
2026-09-25 Fix 18 of 25 fasteners; no screw could ever have reached (#17)
    * Fix perimeter screw joint (Option 1), correct SEAM/TRIM lengths, fix 08's countersink, make check exit codes trustworthy
    PERIM_A/PERIM_B (the reported defect): the face-plate boss reaching
    44.46mm/56.46mm short of the shell wall it screws into. Lengthens the
    boss to reach the shell's own inner wall face (derived from
    PANEL_D/BACK_PLANE_Y, FIT_CLEARANCE short of full contact, never
    restated as a constant), recesses the insert a derived distance from
    the boss's clamping tip so M3x12 gets real ~5mm engagement instead of
    bottoming out, and braces the new ~48-60mm boss with a printed gusset
    fin (tapered, not a bare cantilever -- co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
    [01a-face-plate-screen.step, 01a-face-plate-screen.stl, 01b-face-plate-column.step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]
2026-09-25 Fix unprintable coupon labels: derive stroke width, move off narrow edges (#14)
    Labels were real, valid STEP geometry (confirmed by extra face counts)
    but their strokes (0.006-0.176mm, measured on the printed parts) were
    far under the 0.4mm nozzle's minimum feature size, so the slicer
    silently dropped every one of them -- "a feature that exists in CAD but
    is below the process's minimum feature size is not a feature."
    - Derive LABEL_SIZE_MM from this font's own measured stroke-to-cap-height
    ratio (11.5mm, not the "~6mm" starting estimate) instead of assuming a
    size, with a permanent min_stroke_width_mm() assertion (>= 2x nozzle
    width) run on every label, every regeneration. Confirmed i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
    [A1-face-plate-screen-corner.step, A1-face-plate-screen-corner.stl, A2-back-shell-screen-corner.step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]
2026-09-25 Log plates 1 and 2: the screen module fits together (#18)
    First time 01a and 02a have gone together. Confirms the boss/wall fix, the
    new long perimeter bosses, and the trim rebate removal -- at full scale.
    Records what it does not prove: nothing was screwed together, so the
    fastener-length fix is still unconfirmed.
2026-09-25 Route travels around openings; log the stringing cause (#19)
    Stringing on 02a clusters at the speaker opening and the light vents because
    reduce_crossing_wall was off: travel moves took the straight line across the
    voids, dragging a strand on every layer. Solid areas of the same part are
    clean, which is the tell.
    Turning it on costs about 2% print time. No geometry changes.
    [dial-panel-coupons.3mf, dial-panel-hw-2015.3mf]
2026-09-30 docs: correct the BETA callout to the real print status
    The status block still said nothing had been printed or fitted, which the
    print log has contradicted since 2026-09-22. State where the build actually
    stands -- nine plates printed, screen module fitting, coupons passed, six
    plates pending reprint -- point at the print log, and record that this does
    not go to the print marketplaces until a fully working unit exists.
2026-10-04 Dial OS: build the image by patching Raspberry Pi OS, not rebuilding it (#16)
    A method for shipping a Dial Panel image without taking on a distribution.
    Dial OS is the official Raspberry Pi OS release with a short patch: the
    four device-tree overlays the device's own docs/config.txt already
    specifies, a user with the right groups, two systemd units and the
    dashboard binary. CustomPiOS opens the released image, runs one chroot
    script in it and repacks it -- minutes on x86_64 in Docker, on the build
    fleet we already have.
    Chosen over the two obvious alternatives for reasons that are about the
    tenth build, not the first. pi-gen would rebuild an entire OS to add four
    config lines. rpi-image-ge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
2026-10-04 docs: record the Trixie ruling (DJ, 2026-10-04); config.txt header now says Trixie
    [config.txt]
